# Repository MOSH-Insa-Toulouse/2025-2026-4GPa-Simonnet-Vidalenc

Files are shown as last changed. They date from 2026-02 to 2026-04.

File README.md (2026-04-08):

# Projet Capteur Low-Cost 4A Génie Physique - Max Simonnet & Basile Vidalenc

## Sommaire
- [Projet Capteur Low-Cost 4A Génie Physique - Max Simonnet \& Basile Vidalenc](#projet-capteur-low-cost-4a-génie-physique---max-simonnet--basile-vidalenc)
  - [Sommaire](#sommaire)
  - [1. Description du projet ](#1-description-du-projet-)
    - [1.1 Caractéristiques et travaux de recherche préliminaires sur le capteur ](#11-caractéristiques-et-travaux-de-recherche-préliminaires-sur-le-capteur-)
    - [1.2 Cours et formation ](#12-cours-et-formation-)
  - [2. Livrables du projet ](#2-livrables-du-projet-)
  - [3. Carte Arduino UNO et code associé ](#3-carte-arduino-uno-et-code-associé-)
  - [4. KiCad ](#4-kicad-)
    - [4.1. Symboles et empreintes des composants ](#41-symboles-et-empreintes-des-composants-)
    - [4.2. Schématique ](#42-schématique-)
    - [4.3. Placement des composants ](#43-placement-des-composants-)
  - [5. Fabrication du shield ](#5-fabrication-du-shield-)
    - [5.1 Réalisation du PCB ](#51-réalisation-du-pcb-)
    - [5.2 Perçage et soudure ](#52-perçage-et-soudure-)
  - [6. Logiciel de simulation LTSpice ](#6-logiciel-de-simulation-ltspice-)
  - [8. Tests et résultats ](#8-tests-et-résultats-)
    - [8.1 Banc de test ](#81-banc-de-test-)
    - [8.2 Résultats obtenus et analyses ](#82-résultats-obtenus-et-analyses-)
    - [8.3 Regard critique sur les résultats ](#83-regard-critique-sur-les-résultats-)
  - [9. Datasheet ](#9-datasheet-)

## 1. Description du projet 

Ce projet s'inscrit dans le cadre de l'unité de formation "Du capteur au banc de test en open source hardware". Ce cours est dispensé en quatrième année au sein du département de Génie Physique de l'INSA Toulouse et a pour but de nous sensibiliser aux différentes étapes de conception et d'analyse utiles à la création d'un capteur.

### 1.1 Caractéristiques et travaux de recherche préliminaires sur le capteur 

Le KTY2000 est un exemple de technologie low-tech à base de graphite. Ce projet s’inspire du travail mené par plusieurs scientifiques et publié dans [cet article](https://www.nature.com/articles/srep03812) en 2014. En effet, les études ont révélé les nombreux avantages du carbone graphite. L’électronique à base de papier attire de plus en plus les ingénieur.es de par sa facilité d’approvisionnement, de fabrication et son faible coût. Il suffit dans notre cas de déposer une fine couche de graphite sur le substrat naturellement poreux pour former la base du capteur. Les mines de crayon sont constituées de réseaux percolés de fines poudres de graphite liées entre elles par des argiles, permettant d’obtenir après dépôt de fins films conducteurs non fabriqués en laboratoire. 

Le système à l’étude est granulaire, autrement dit il existe une dépendance entre la conductivité électrique (notamment par effet tunnel) et l’espace moyen entre les nanoparticules de graphite. Ainsi, une déformation de la feuille de papier va modifier la conductivité globale de la couche de graphite, induisant des changements de résistances réversibles lors des déformations en compression ou en traction. Ceci constitue en fait le principe d'une jauge de contrainte. 
L’expérience est réalisée avec différentes duretés de mine de crayon (2H, HB, 2B). Les mesures de résistance pour chaque crayon sont réalisées en fonction de différents rayons de courbure (soit la déformation) ou de l’angle de flexion de notre capteur. Cela permet une caractérisation complète de chaque type de crayon et ainsi de notre capteur. 

Dans notre cas, les traces de crayon sont déposées sur du papier comme vu ci-dessous. Une fois colorié, le capteur est connecté à un système de mesures externe via des pinces crocodiles reliées à un PCB et branché sur une carte Arduino Uno.

<p align="center">

### 1.2 Cours et formation 

Pour mener ce projet, nous avons d'abord suivi différents cours et TPs.
- Introduction à la chaîne de mesure
- TP développement d'un capteur à jauge de contrainte à base de crayon graphite
- TP conception d'un circuit analogique pour interfacer le capteur à jauge de contrainte
- TP programmation de microcontrôleurs et développement d'un matériel open source
- TP LTSpice afin de simuler le fonctionnement du circuit électronique comprenant la jauge de contrainte
- TP shield électronique PCB dédié à l'interface du capteur de contrainte
- TP réalisation du banc de test de la jauge de contrainte
- Cours fiche technique de la jauge de contrainte
- Cours Github

<p align="center">

## 2. Livrables du projet 

* Un shield PCB devra être designé et fabriqué. Il sera ensuite connecté à une plaque Arduino UNO. Le shield doit contenir au minimum un amplificateur transimpédence, un module Bluetooth, un écran OLED et un encodeur rotatoire pour la calibration du capteur.

* La carte Arduino fonctionnera avec un code permettant de mesurer la containte appliquée sur le capteur. La carte devra aussi communiquer avec le module Bluetooth, et contrôler et communiquer avec l'écran OLED grâce à l'encodeur rotatoire.

* Une application Android APK
* Un protocole de test
* La datasheet du capteur de contrainte

## 3. Carte Arduino UNO et code associé 

Le code Arduino est consultable [ici]().
Ce code permet la réception des mesures faites par les deux capteurs, la conversion résistance-angle du flex-sensor et celle tension-résistance pour le KTY2000, la gestion de l'affichage sur l'écran OLED et l'envoi de données via un port série.

## 4. KiCad 

Voici la liste des différents composants présents sur notre PCB :

- _x2 résistance 100kΩ_
- _x1 résistance 47kΩ_
- _x1 résistance 10kΩ_
- _x1 résistance 1kΩ_
- _x1 résistance variable MCP41010_
- _x1 capacité 1μF_
- _x2 capacité 100nF_
- _x1 amplificateur opérationnel LTC1050_
- _x1 écran OLED I2C 1306_
- _x1 encodeur rotatoire_
- _x1 servo-moteur_
- _x1 capteur graphite_

### 4.1. Symboles et empreintes des composants 
 
* Amplificateur LTC1050
* MCP41010
* Ecran OLED
* Flex sensor
* Bluetooth HC-05

### 4.2. Schématique 
 
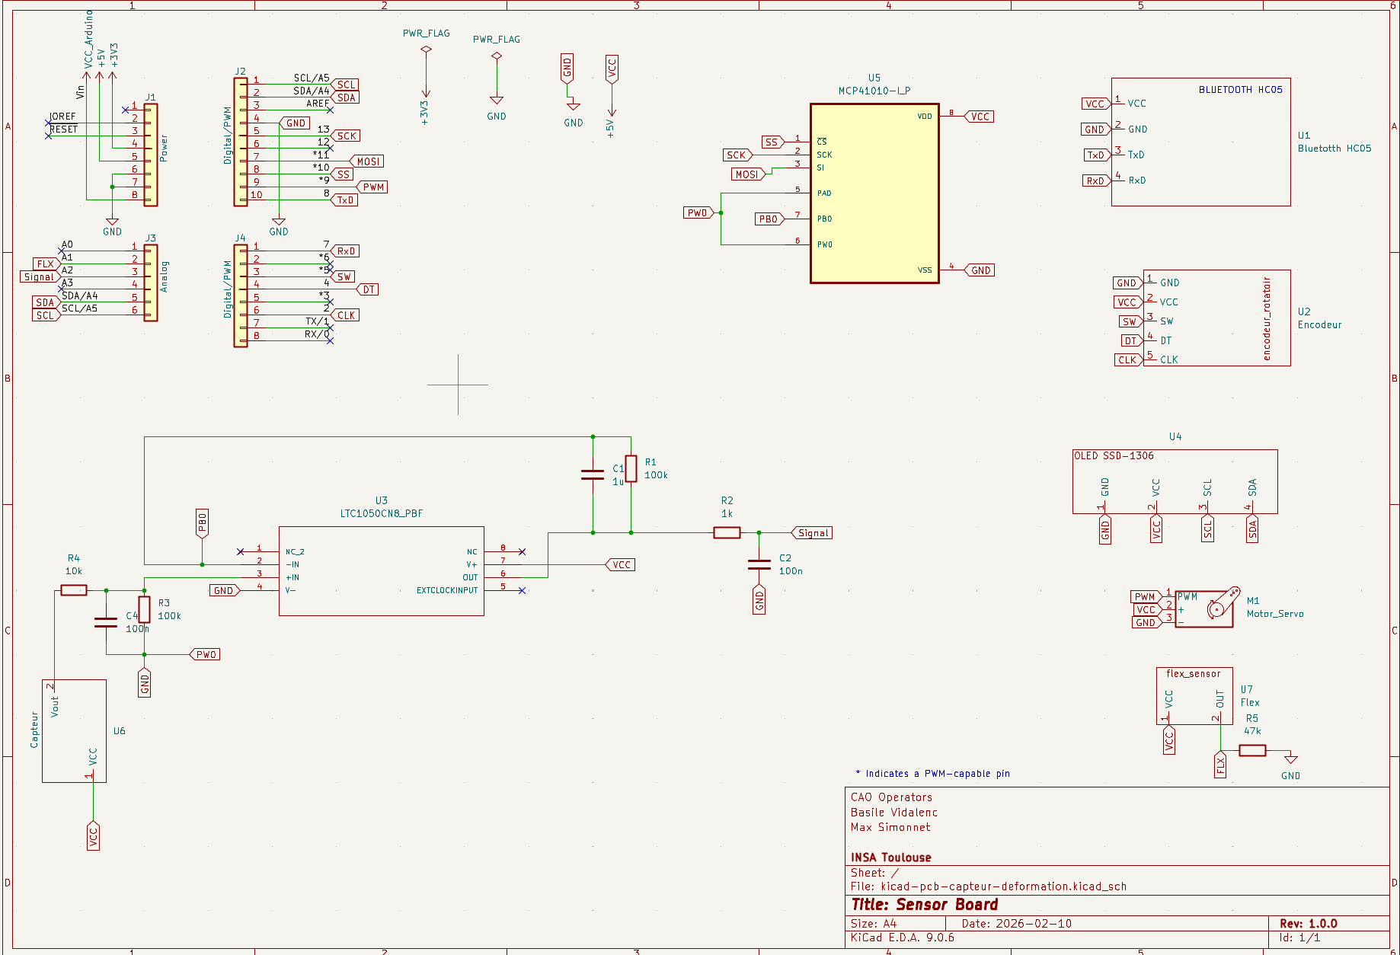
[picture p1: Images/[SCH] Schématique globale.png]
<p align="center">

* Amplificateur LTC1050
<p> 
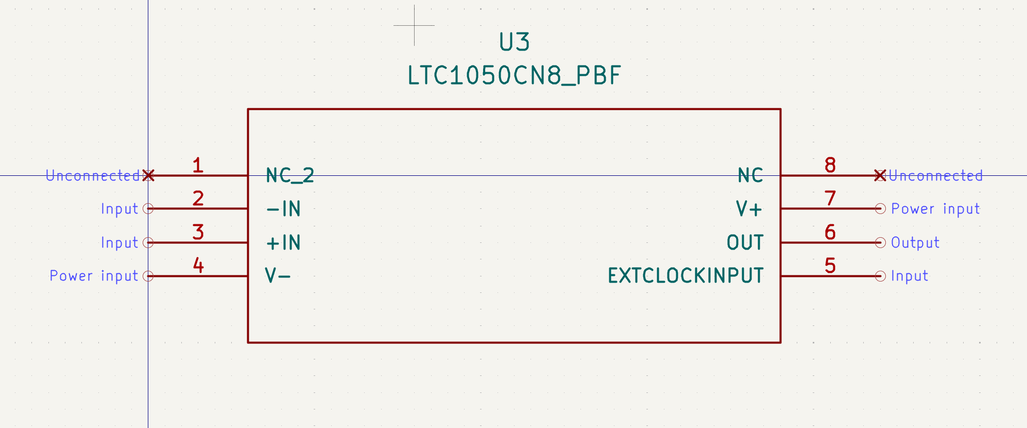
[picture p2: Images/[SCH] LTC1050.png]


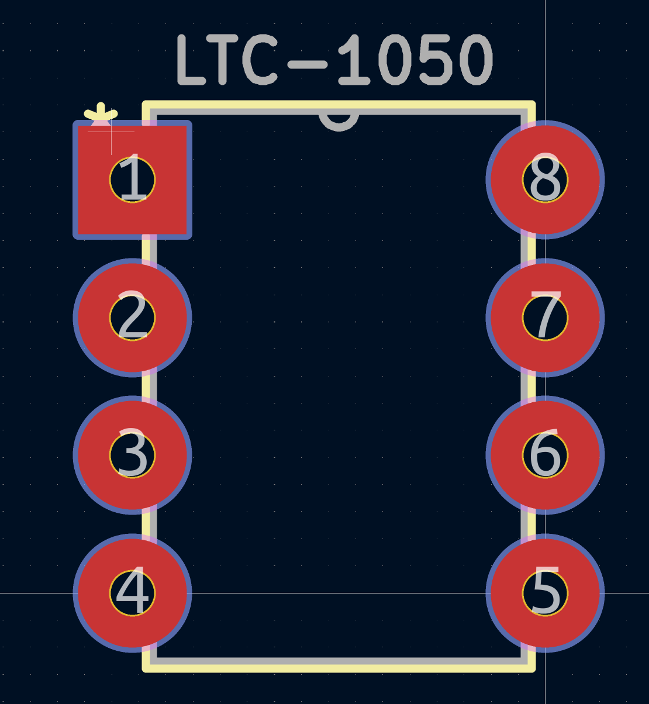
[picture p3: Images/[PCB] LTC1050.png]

</p>

* MCP41010
 <p> 
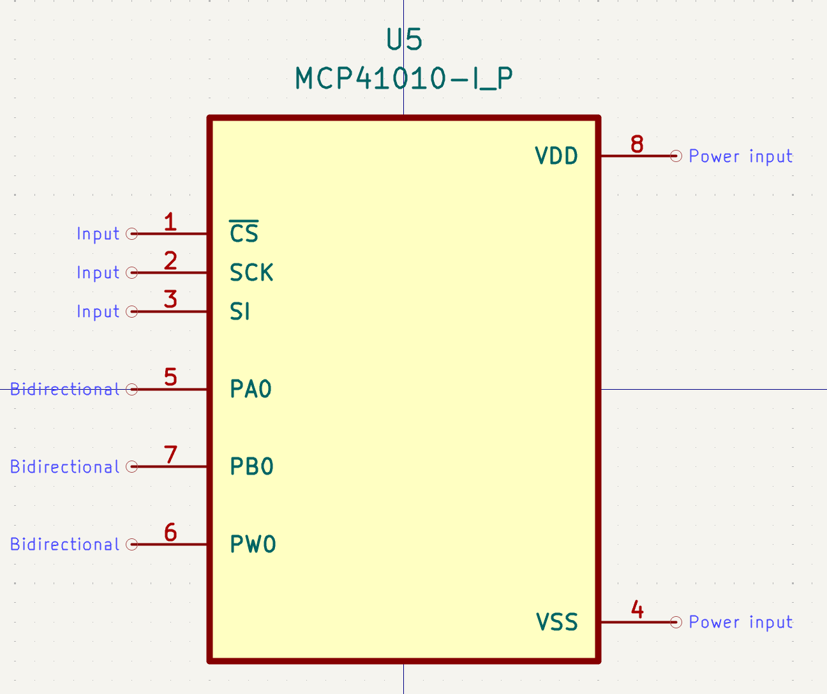
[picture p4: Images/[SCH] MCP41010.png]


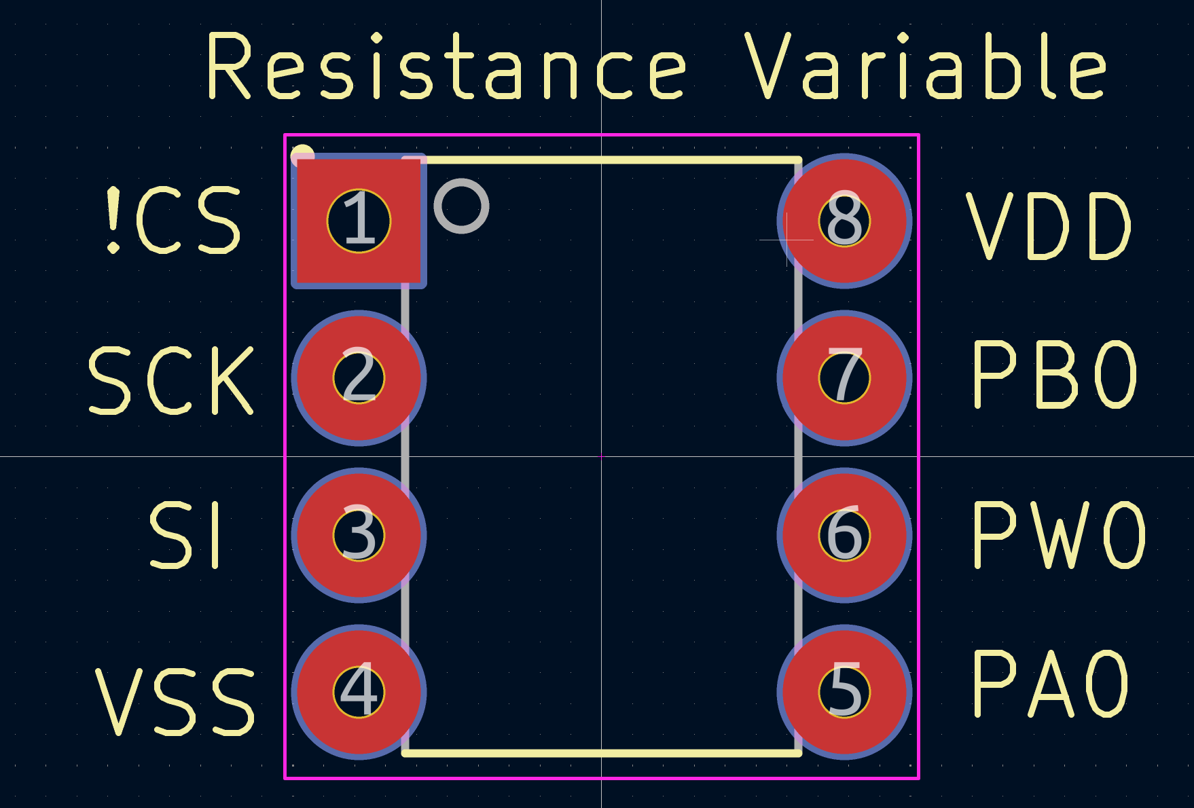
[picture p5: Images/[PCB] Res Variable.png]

</p>

* Ecran OLED
 <p> 
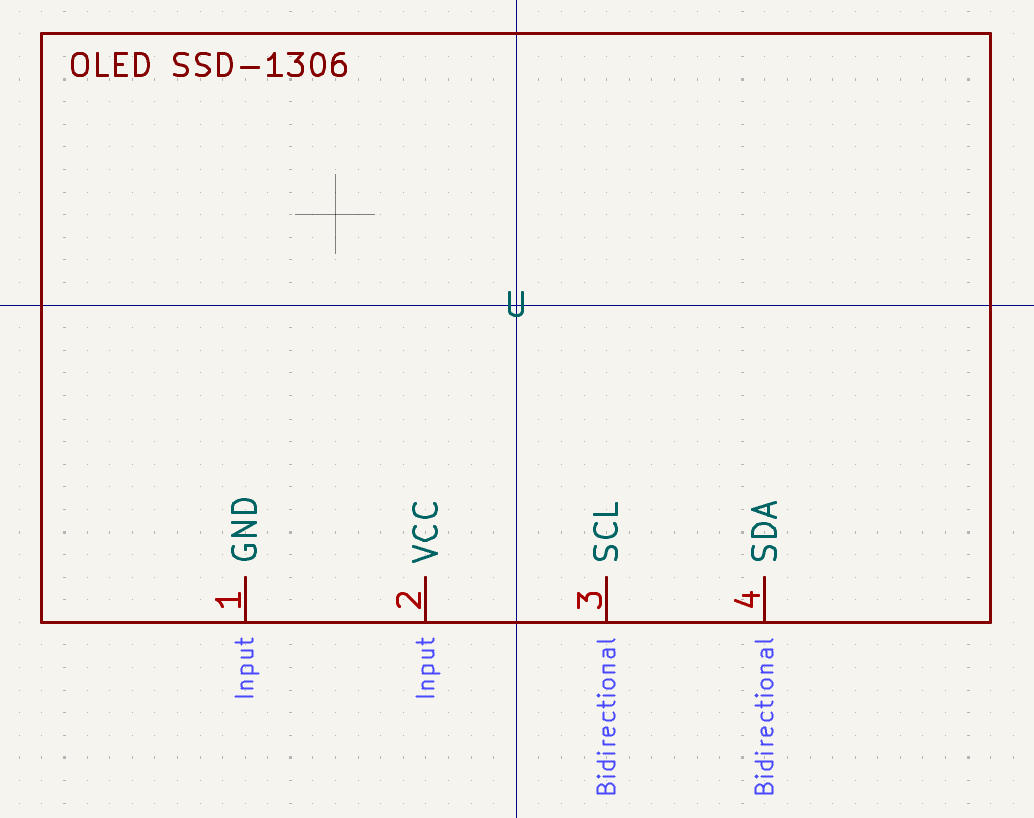
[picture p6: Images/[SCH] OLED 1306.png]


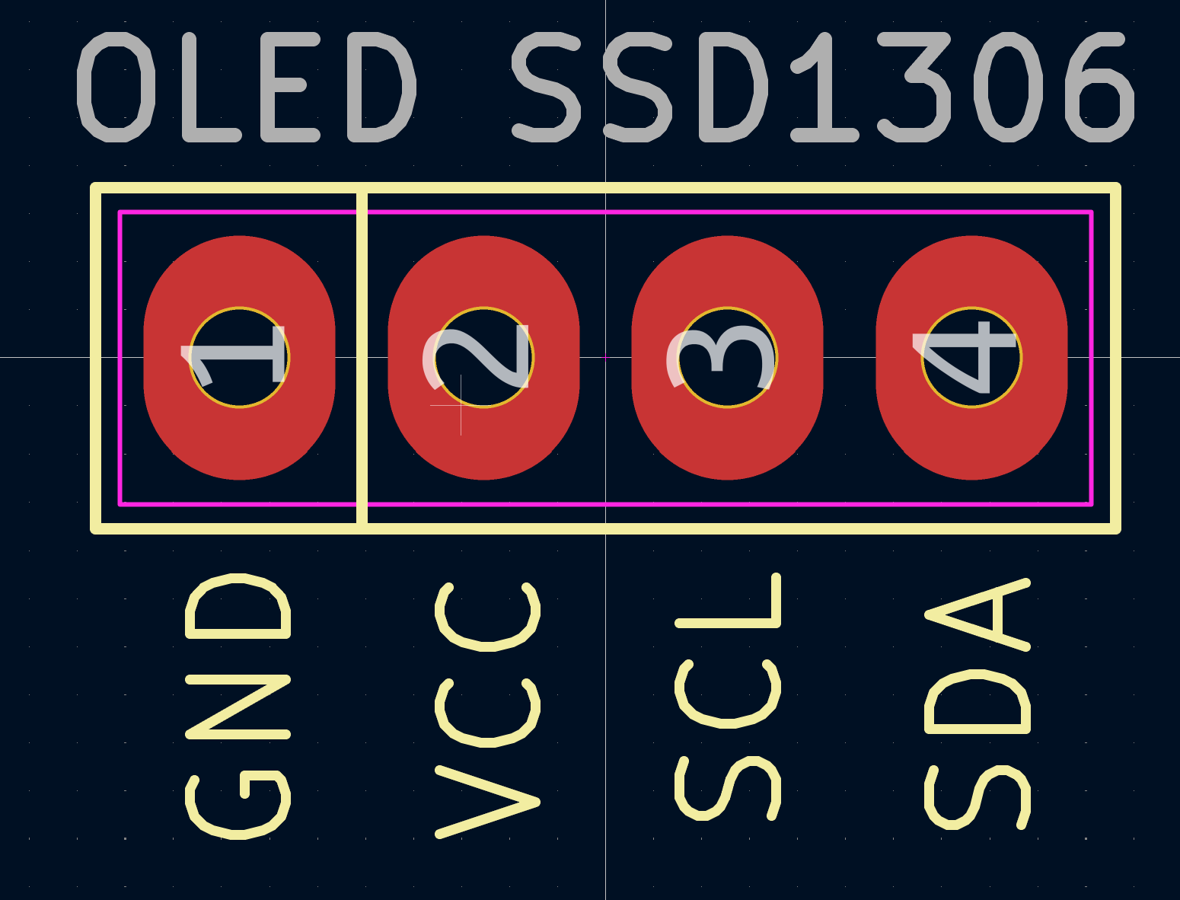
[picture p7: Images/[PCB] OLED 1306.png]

</p>

* Flex sensor
 <p> 
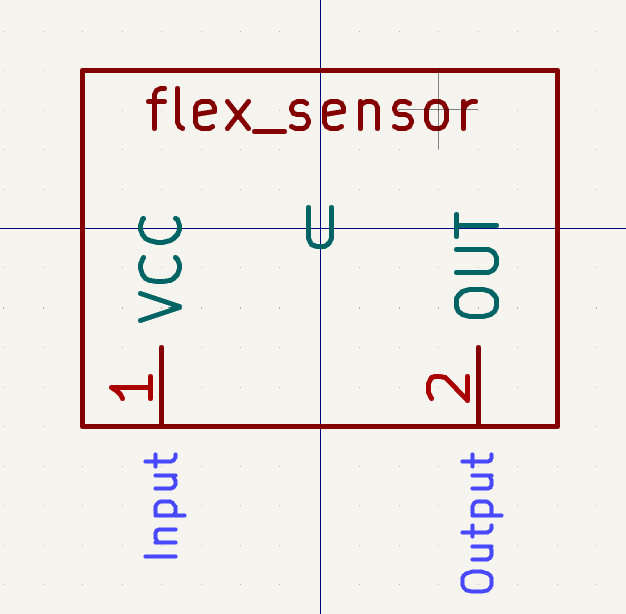
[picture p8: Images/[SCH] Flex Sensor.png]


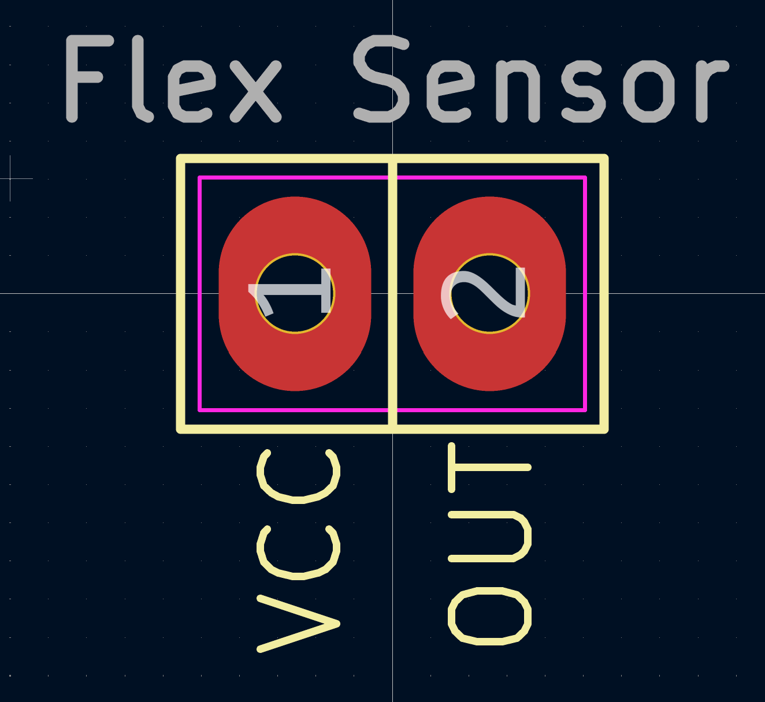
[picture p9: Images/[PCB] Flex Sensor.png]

</p>

* Bluetooth HC-05
 <p> 
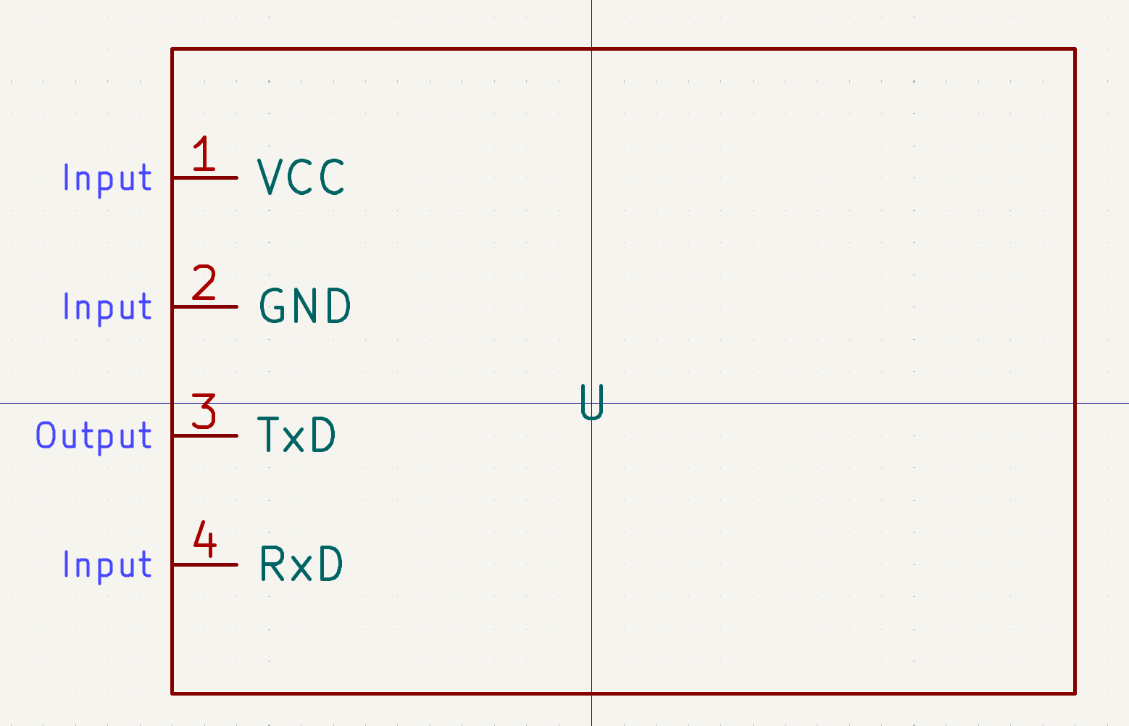
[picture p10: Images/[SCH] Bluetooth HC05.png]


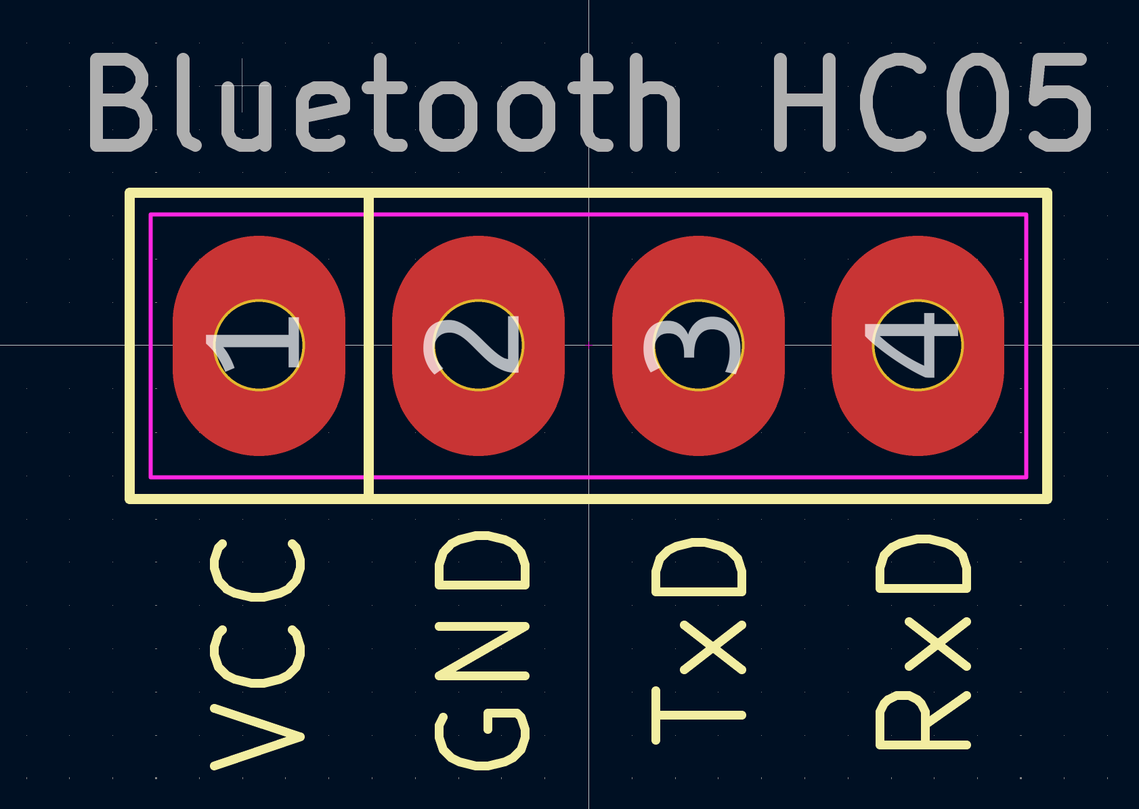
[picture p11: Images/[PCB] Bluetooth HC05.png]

</p>

### 4.3. Placement des composants 
 
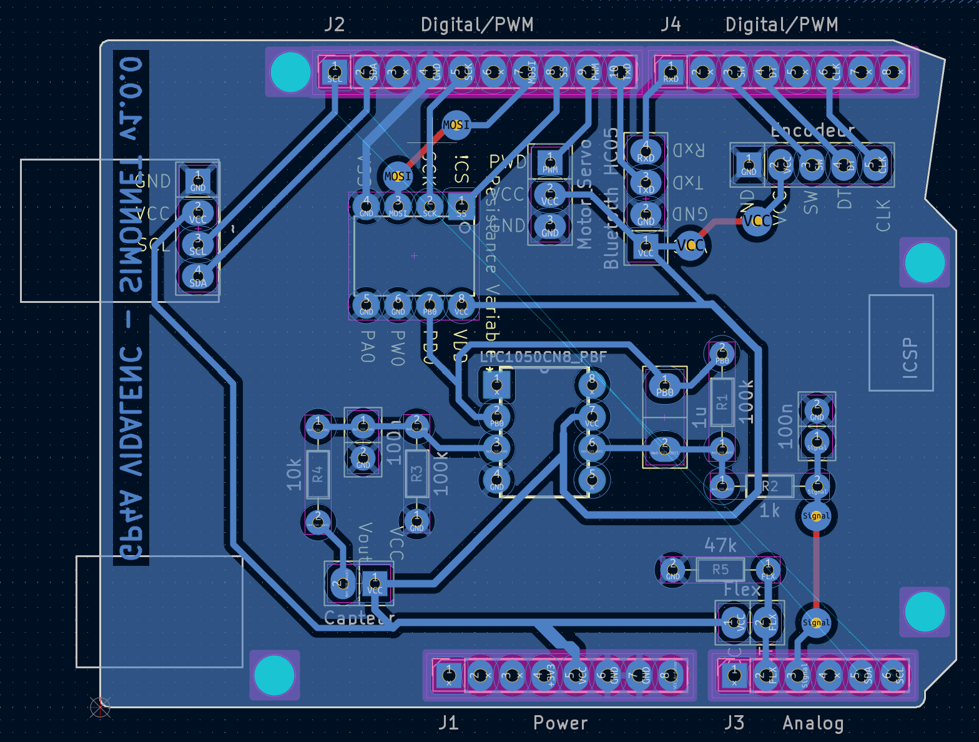
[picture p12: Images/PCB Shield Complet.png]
<p align="center">

## 5. Fabrication du shield 
 
### 5.1 Réalisation du PCB 

Le PCB a été fabriqué grâce au matériel mis à disposition au Génie Physique et au Génie Électrique et Informatique de l'INSA Toulouse. Les manipulations ont été faites avec l'aide de Catherine Crouzet. La modélisation du PCB fait sur [KiCad]() a été imprimée sur du papier calque tranparent. Ce motif a été ensuite transféré par UVs sur la plaquette d'epoxy finement recouverte d'une couche de cuivre. À l'aide d'un révelateur, la partie non insolée de la résine a été retirée. La plaquette d'expoxy a été ensuite placée dans un bain de perchlorure de fer pour que le cuivre non protégé par la résine soit retiré de la plaquette. Enfin, la plaque a été nettoyée des dernières traces de résine avec de l'acétone.

Par soucis de convention, les pattes "1" de chaque composant sont en forme de carré

### 5.2 Perçage et soudure 

⌀ 1.0mm : Broches de connexion de la carte Arduino Uno

⌀ 0.8mm : Circuit intérieur du PCB 

## 6. Logiciel de simulation LTSpice 
 
L'ensemble de notre circuit électronique a été simulé sur le logiciel LTSpice afin de comprendre et d'analyser son comportement dans des conditions réelles de valeurs de tension. Les différentes simulations ont permis d'une part de vérifier le bon fonctionnement du circuit et de chacun des composants intégrés, et d'autre part de comprendre l'utilité de chacun. Les images ci-dessous représentent la schématique du circuit. Se référer à la [datasheet] pour de plus amples informations.

## 8. Tests et résultats 

Setup d'utilisation du KTY2000.

### 8.1 Banc de test 

### 8.2 Résultats obtenus et analyses 

Les deux graphes suivant représentent la variation de la résistance relative (en %) en fonction de la déformation appliquée - compression et traction.

Les mines les plus tendres contiennent une proportion plus élevée de particules de graphite. C’est donc pour cette raison que les traces de ce type de crayon paraissent plus foncées sur le papier. À l’inverse, les mines les plus dures contiennent beaucoup de liants argileux et apparaissent plus claires. Cela explique également que les résistances de mines de crayon les plus tendres sont plus faibles que les mines de crayon les plus dures. En effet, sous la traction, les particules de graphite sont davantage écartées les unes des autres favorisant la déconnexion des voies de conduction : le courant est donc minime, la résistance quant à elle augmente.  Sous compression, les particules de graphite contenues dans la trace de crayon se rapprochent, facilitant la conduction du courant à travers le réseau de percolation : la résistance s’abaisse naturellement.

Cette caractéristique est illustrée à travers la variation relative de résistance en fonction de la déformation du capteur. En effet, un crayon qui contient moins de particules de graphite comme le 2H dépose naturellement moins de graphite sur le substrat. Les variations de résistance sont donc plus significatives comme beaucoup de chemins de percolations sont créés ou rompus contrairement au 2B où les déformations n’induisent que de faibles variations relatives de résistance.
 
Il est également notable que le comportement en compression du flex-sensor se rapproche de celui du KTY2000. Nous pouvons en conclure que notre capteur graphite présente des similarités de fonctionnnement qu'un capteur industriel. **Cela confirme l'idée que le low-tech est une alternative pertinente pour le futur de l'industrie.**

### 8.3 Regard critique sur les résultats 
 
Il est important de souligner la variabilité des conditions expérimentales. Entre chaque relevé de points et malgré le fait que les pinces crocodiles sans dents étaient bien fixées, il se peut que l’attache du capteur ait bougée. Les résultats sont imprécis et pour certains discutables au vu de la qualité du montage mais suivent tout de même les lois physiques. 

Nous pourrions amener plusieurs pistes d'améliorations à notre projet :

- Améliorer notre banc de test afin de garantir des résultats optimaux mais surtout pour augmenter sa durée de vie et sa résistance. Par exemple, nous pourrions concevoir de le fabriquer par l'intermédiaire d'une imprimante 3D. 

- Améliorer le setup expérimental en commençant par l'ergonomie de notre PCB afin de le rendre plus fonctionnel pour la réalisation des mesures de résistance. Penser à un meilleur emplacement pour les différents composants, à un système d'accroche pour l'écran OLED, mais aussi pour les pinces crocodile dans le but de limiter le plus possible la variabilité des conditions expérimentales. 

## 9. Datasheet 
 
La datasheet du KTY2000 est consultable [ici]. Elle reprend tous les concepts physiques ainsi que les résultats de mesures et leur analyse. D'autres courbes illustrant la variation de résistance en fonction de l'angle de flexion y figurent, venant compléter les affirmations énoncées tout au long de ce rendu.

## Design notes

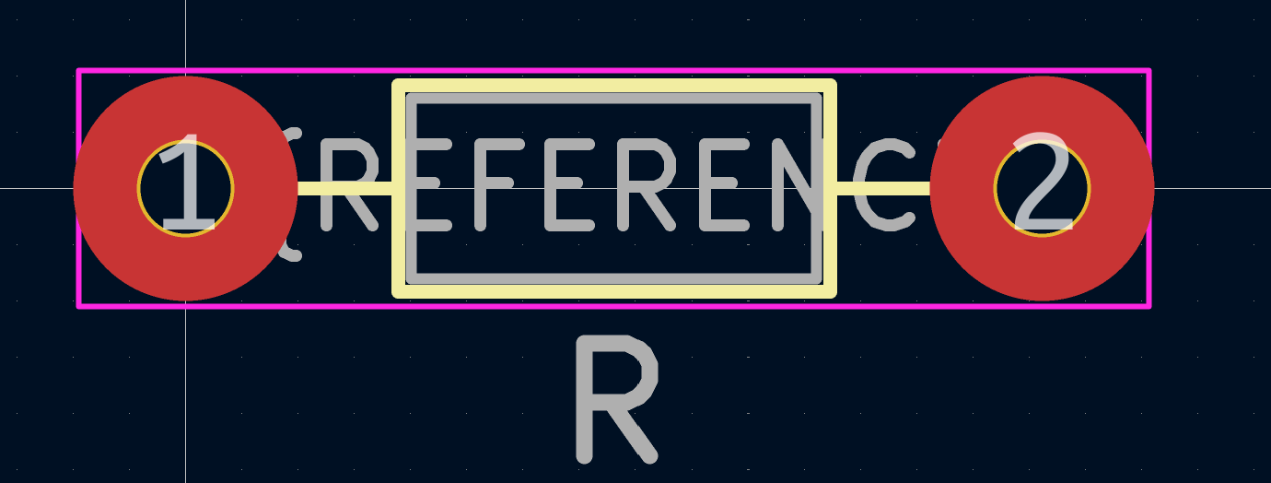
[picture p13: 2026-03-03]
Images/[PCB] Resistance.png

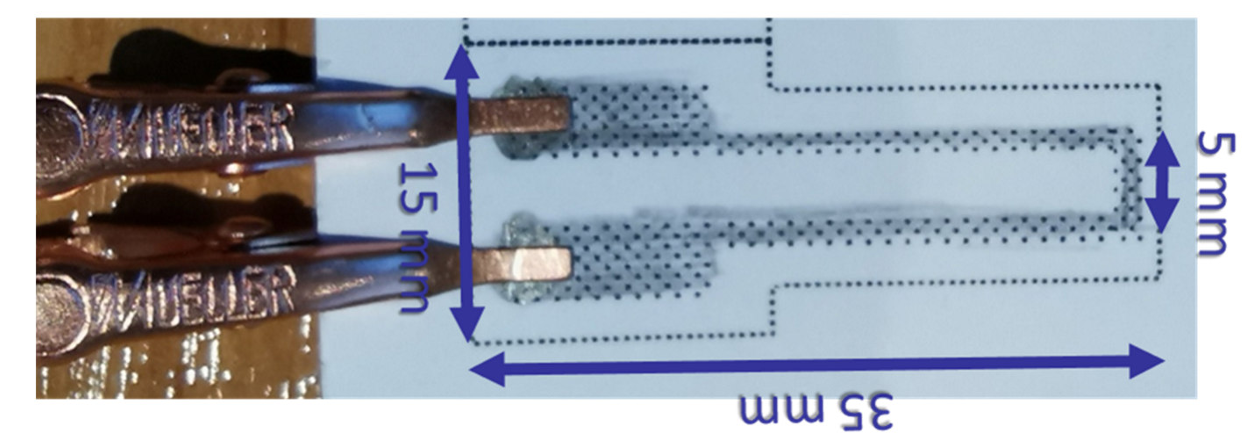
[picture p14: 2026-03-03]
Images/Dimensions Capteur graphite.png

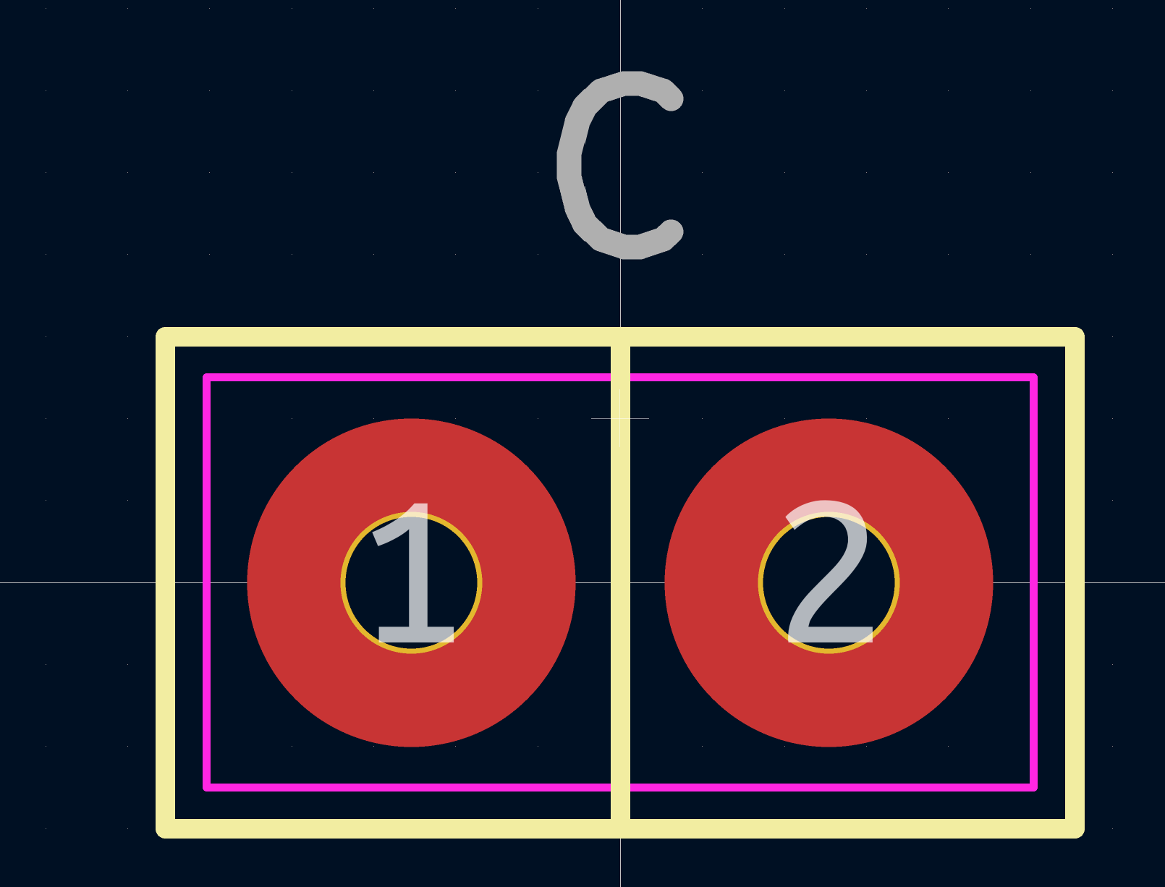
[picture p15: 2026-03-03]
Images/[PCB] Condo souple.png

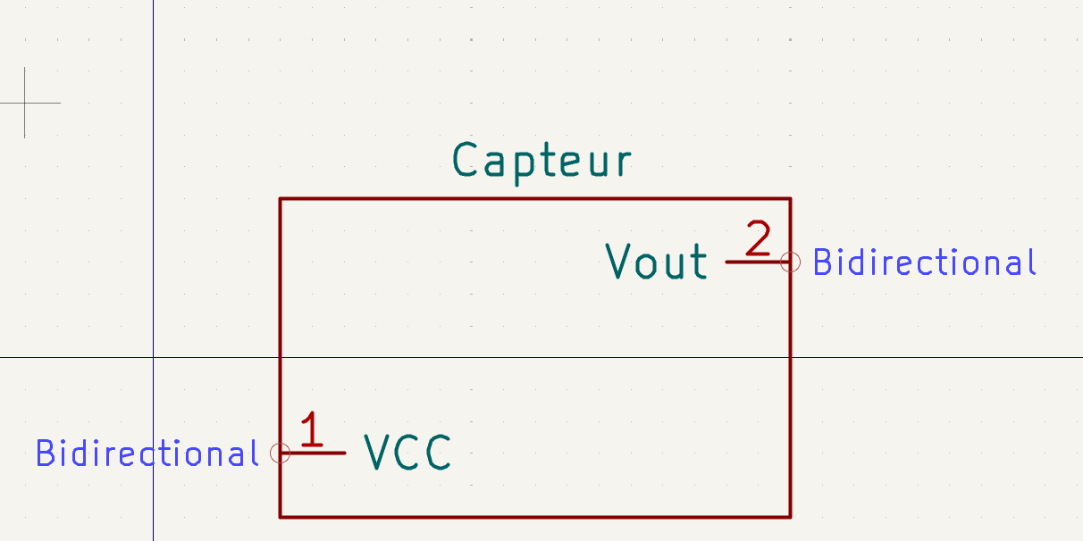
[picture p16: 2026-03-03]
Images/[SCH] Capteur graphite.png

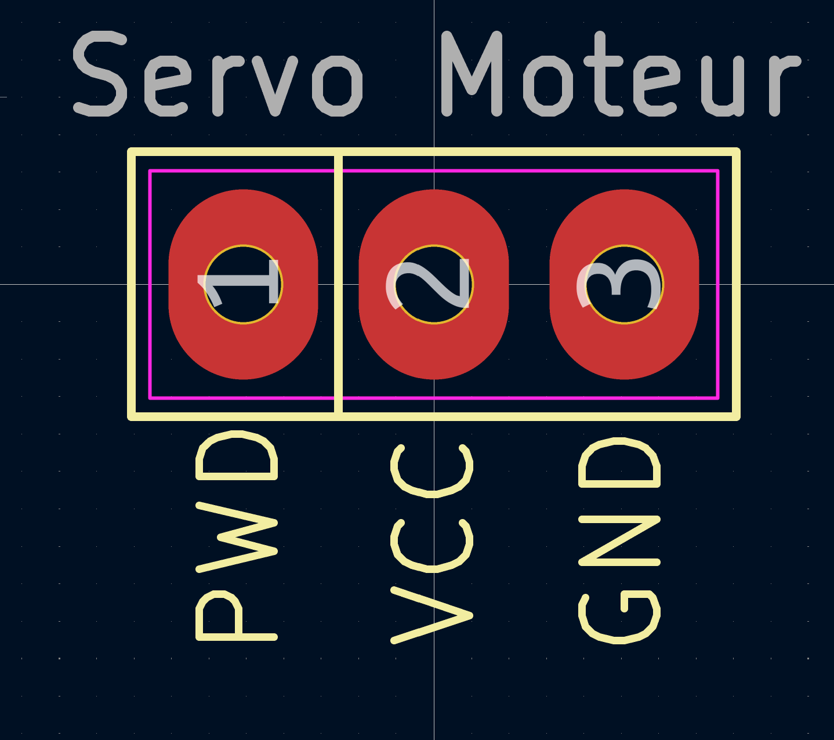
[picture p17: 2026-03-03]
Images/[PCB] Servo-Moteur.png

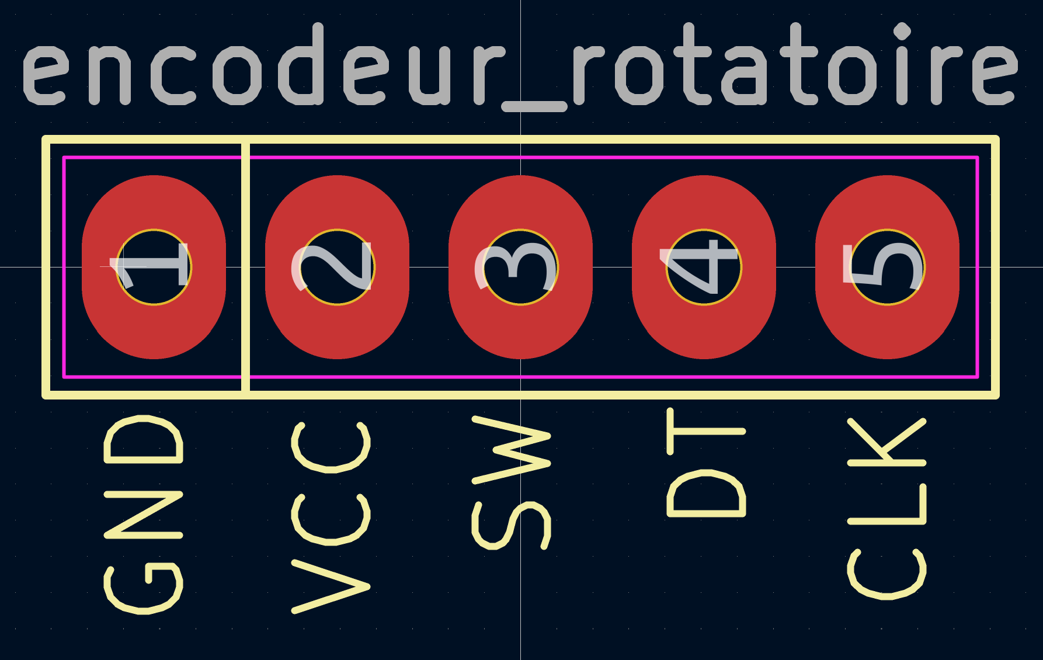
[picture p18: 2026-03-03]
Images/[PCB] Encodeur rotatoire.png

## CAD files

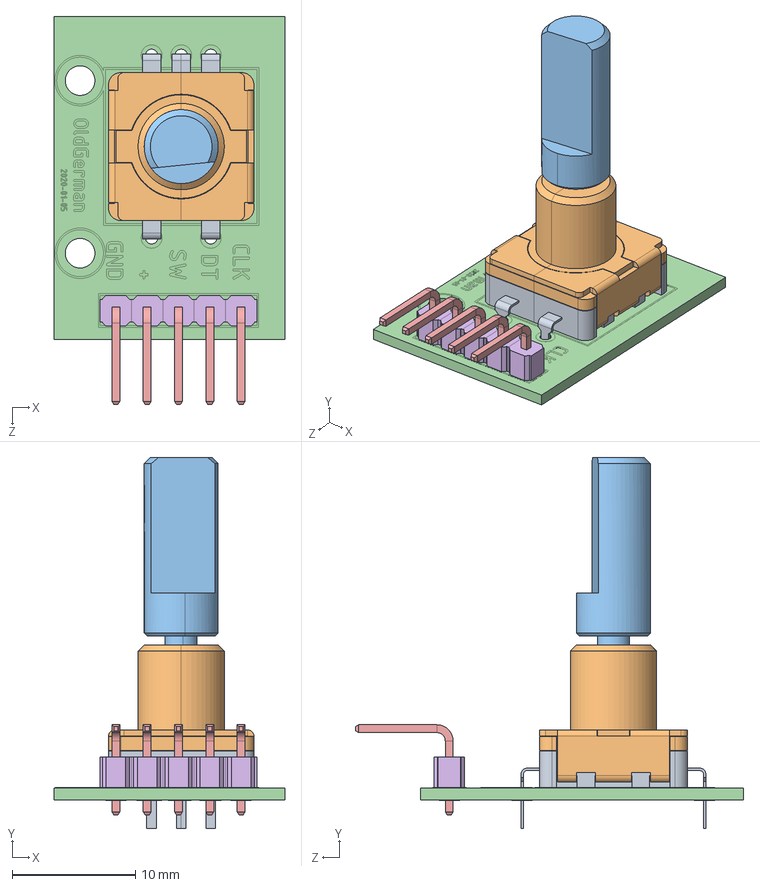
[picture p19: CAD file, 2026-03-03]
kicad-pcb-capteur-deformation/encodeur-rotatoire/KY-040 Rotary Encoder.STEP
18.7 x 30.1 x 31.5 mm
Rotary Encoder
D-handle
pcb
2.54 5PIN 90

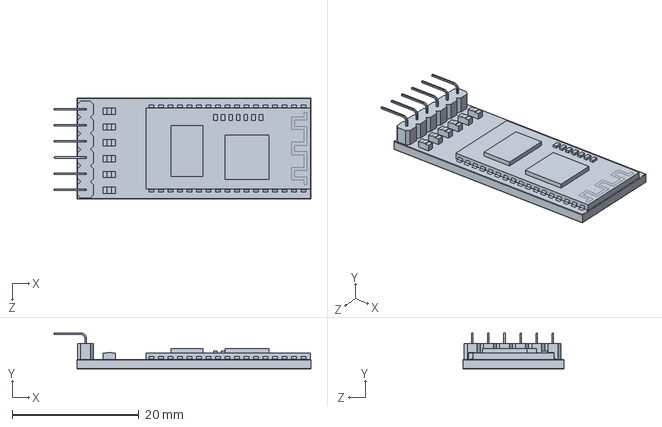
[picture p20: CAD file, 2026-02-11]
kicad-pcb-capteur-deformation/hc05-bluetooth/HC05.STEP
40.6 x 5.67 x 16.0 mm

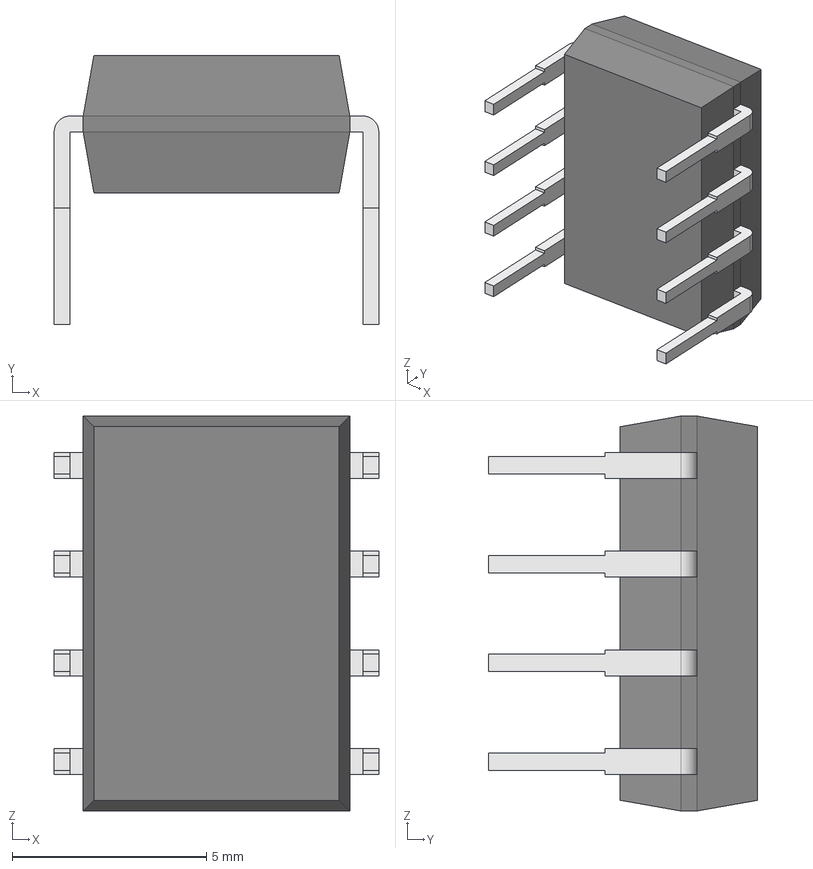
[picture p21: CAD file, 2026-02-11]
kicad-pcb-capteur-deformation/LTC1050CN8_PBF/LTC1050CN8_PBF.step
8.35 x 6.93 x 10.2 mm
Body001 (Mirror #1) x 5

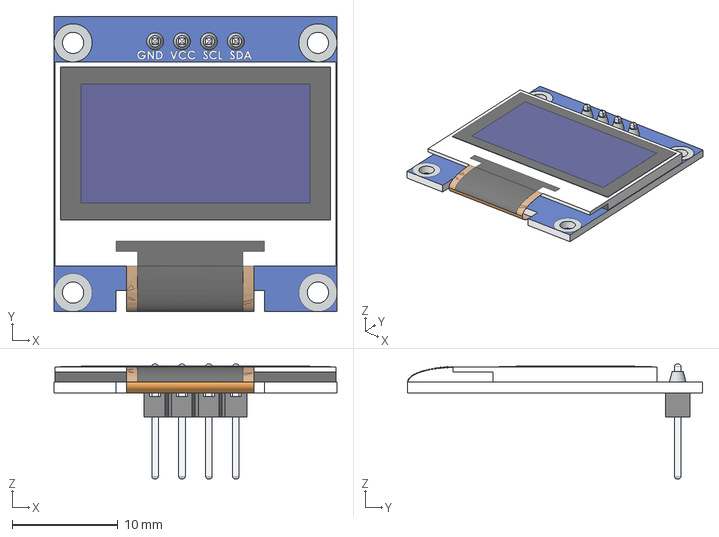
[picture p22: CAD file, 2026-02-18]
kicad-pcb-capteur-deformation/OLED SSD1306/OLED-128x64-0.96.step
26.7 x 27.9 x 10.8 mm

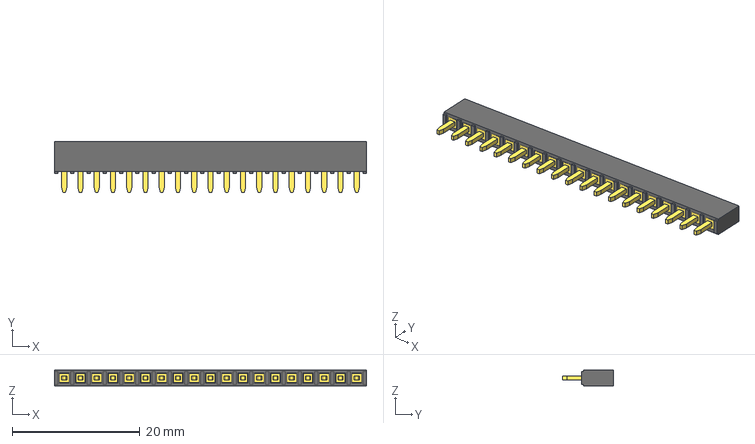
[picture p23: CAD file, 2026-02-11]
kicad-pcb-capteur-deformation/pin-header-female-2-54mm-different-pin-numbers-1.snapshot.4/19-Pin Header - Female - 2.54mm.step
48.8 x 8.00 x 2.50 mm

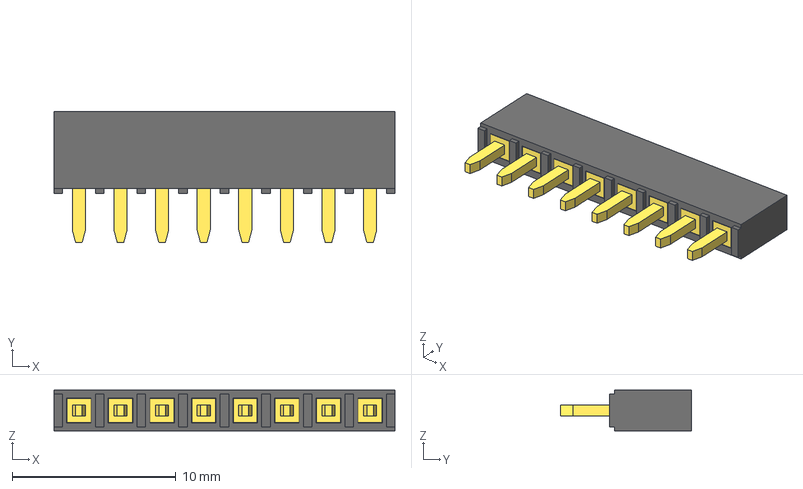
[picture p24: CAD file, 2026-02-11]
kicad-pcb-capteur-deformation/pin-header-female-2-54mm-different-pin-numbers-1.snapshot.4/8-Pin Header - Female - 2.54mm.step
20.8 x 8.00 x 2.50 mm

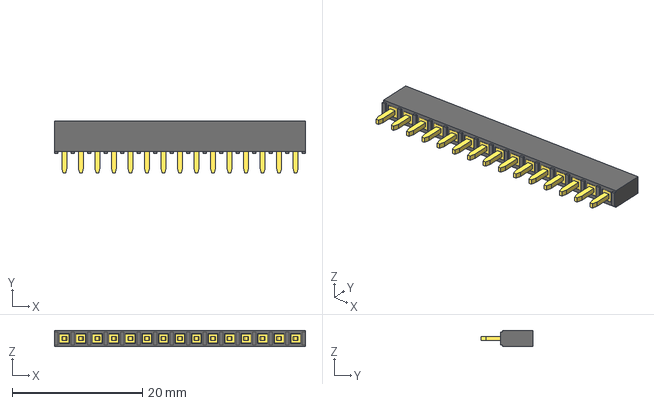
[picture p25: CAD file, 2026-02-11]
kicad-pcb-capteur-deformation/pin-header-female-2-54mm-different-pin-numbers-1.snapshot.4/15-Pin Header - Female - 2.54mm.step
38.6 x 8.00 x 2.50 mm

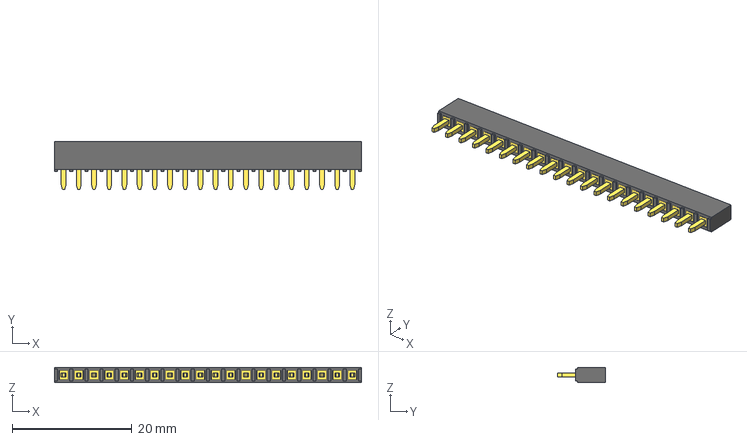
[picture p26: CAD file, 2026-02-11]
kicad-pcb-capteur-deformation/pin-header-female-2-54mm-different-pin-numbers-1.snapshot.4/20-Pin Header - Female - 2.54mm.step
51.3 x 8.00 x 2.50 mm

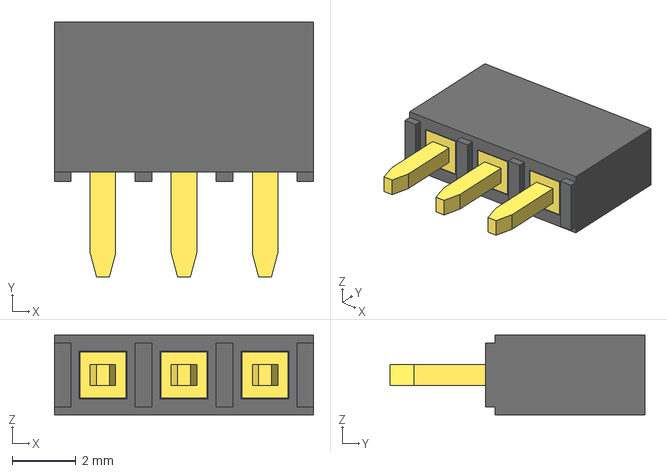
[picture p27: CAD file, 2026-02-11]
kicad-pcb-capteur-deformation/pin-header-female-2-54mm-different-pin-numbers-1.snapshot.4/3-Pin Header - Female - 2.54mm.step
8.12 x 8.00 x 2.50 mm

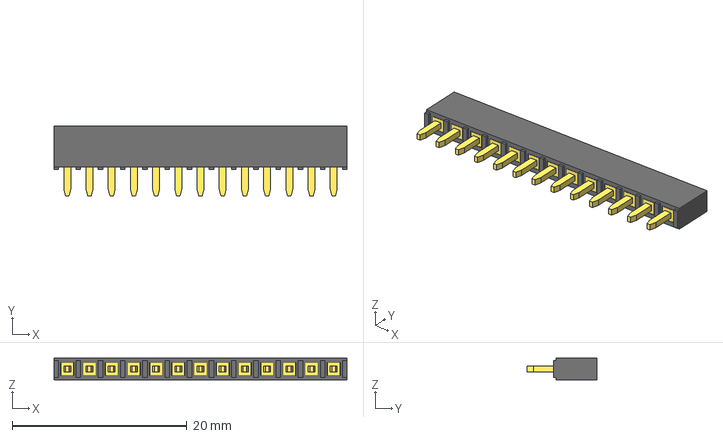
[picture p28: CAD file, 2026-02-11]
kicad-pcb-capteur-deformation/pin-header-female-2-54mm-different-pin-numbers-1.snapshot.4/13-Pin Header - Female - 2.54mm.step
33.5 x 8.00 x 2.50 mm

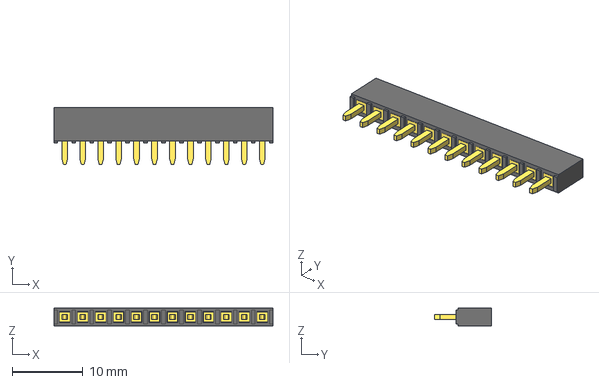
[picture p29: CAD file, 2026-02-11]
kicad-pcb-capteur-deformation/pin-header-female-2-54mm-different-pin-numbers-1.snapshot.4/12-Pin Header - Female - 2.54mm.step
31.0 x 8.00 x 2.50 mm

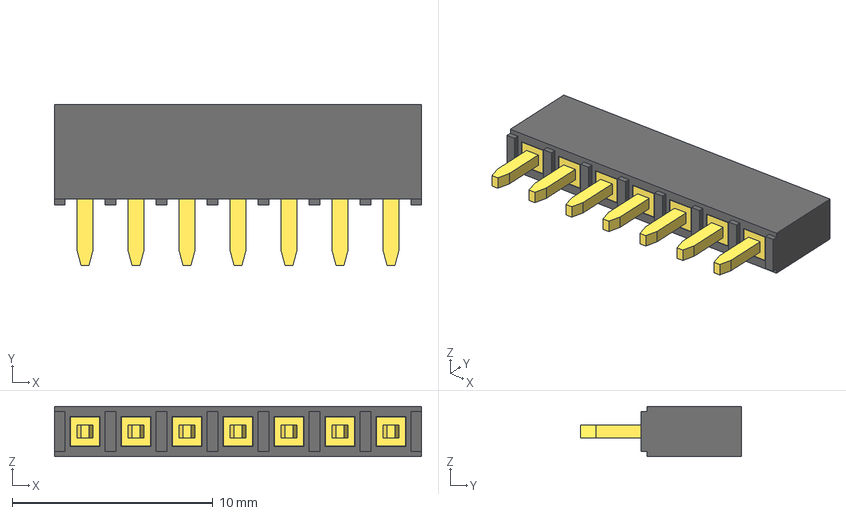
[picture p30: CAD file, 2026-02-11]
kicad-pcb-capteur-deformation/pin-header-female-2-54mm-different-pin-numbers-1.snapshot.4/7-Pin Header - Female - 2.54mm.step
18.3 x 8.00 x 2.50 mm

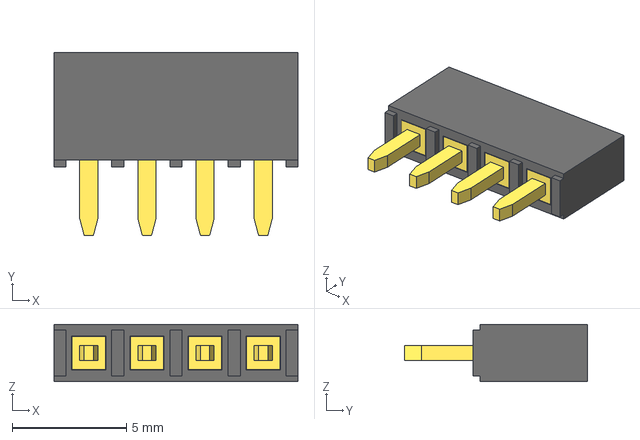
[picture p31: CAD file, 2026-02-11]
kicad-pcb-capteur-deformation/pin-header-female-2-54mm-different-pin-numbers-1.snapshot.4/4-Pin Header - Female - 2.54mm.step
10.7 x 8.00 x 2.50 mm

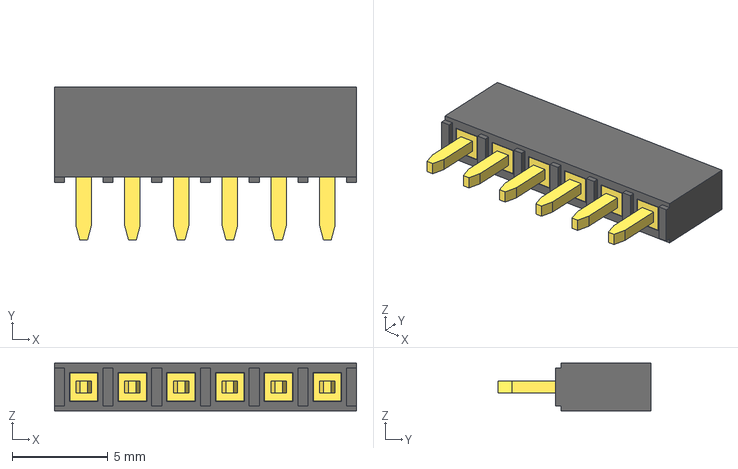
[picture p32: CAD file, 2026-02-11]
kicad-pcb-capteur-deformation/pin-header-female-2-54mm-different-pin-numbers-1.snapshot.4/6-Pin Header - Female - 2.54mm.step
15.7 x 8.00 x 2.50 mm

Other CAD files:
kicad-pcb-capteur-deformation/pin-header-female-2-54mm-different-pin-numbers-1.snapshot.4/14-Pin Header - Female - 2.54mm.step
kicad-pcb-capteur-deformation/pin-header-female-2-54mm-different-pin-numbers-1.snapshot.4/2-Pin Header - Female - 2.54mm.step
kicad-pcb-capteur-deformation/pin-header-female-2-54mm-different-pin-numbers-1.snapshot.4/10-Pin Header - Female - 2.54mm.step
kicad-pcb-capteur-deformation/pin-header-female-2-54mm-different-pin-numbers-1.snapshot.4/11-Pin Header - Female - 2.54mm.step
kicad-pcb-capteur-deformation/MCP41010-I_P/MCP41010-I_P.step
kicad-pcb-capteur-deformation/pin-header-female-2-54mm-different-pin-numbers-1.snapshot.4/16-Pin Header - Female - 2.54mm.step
kicad-pcb-capteur-deformation/pin-header-female-2-54mm-different-pin-numbers-1.snapshot.4/17-Pin Header - Female - 2.54mm.step
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

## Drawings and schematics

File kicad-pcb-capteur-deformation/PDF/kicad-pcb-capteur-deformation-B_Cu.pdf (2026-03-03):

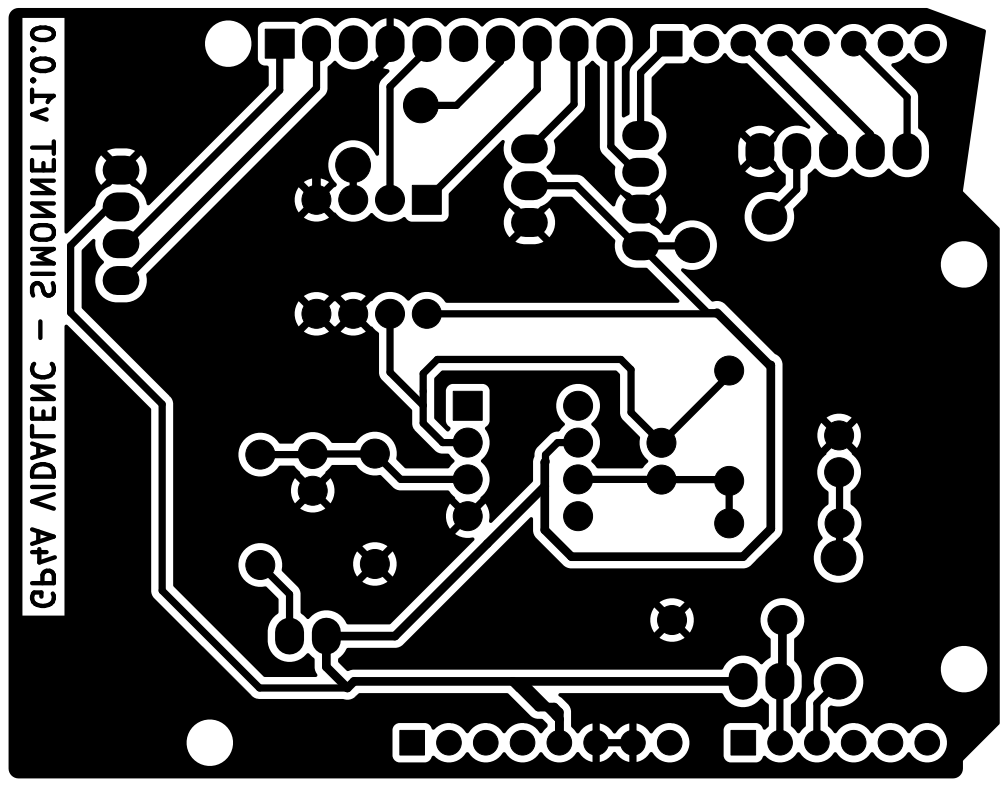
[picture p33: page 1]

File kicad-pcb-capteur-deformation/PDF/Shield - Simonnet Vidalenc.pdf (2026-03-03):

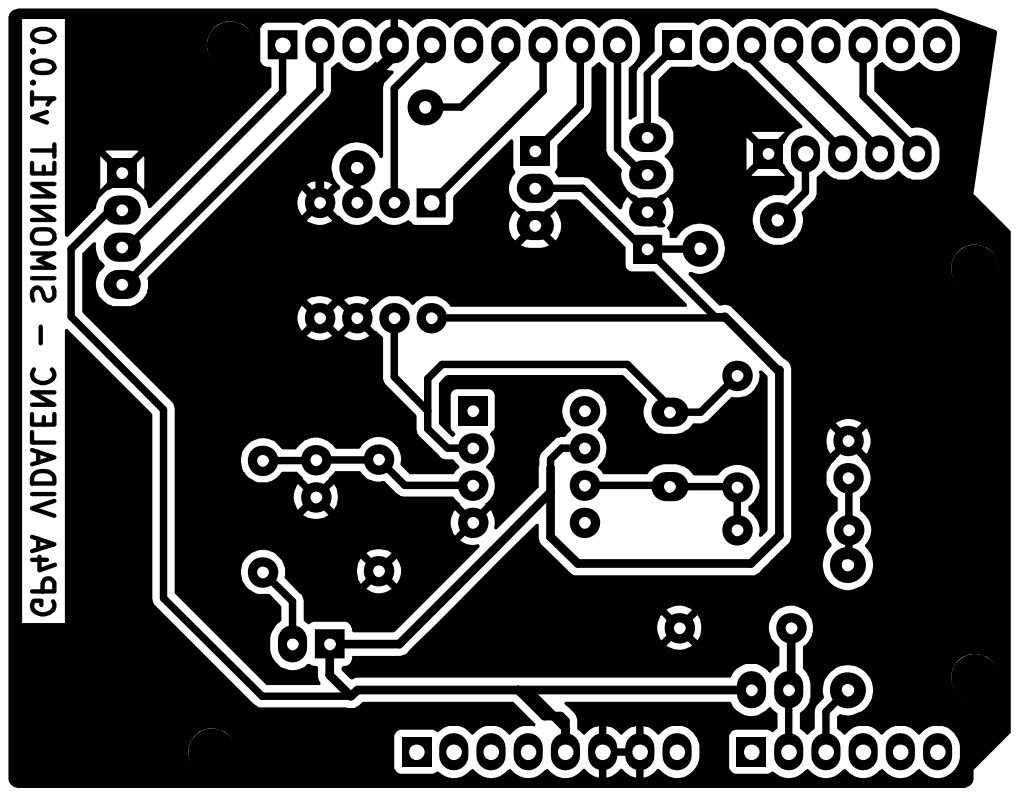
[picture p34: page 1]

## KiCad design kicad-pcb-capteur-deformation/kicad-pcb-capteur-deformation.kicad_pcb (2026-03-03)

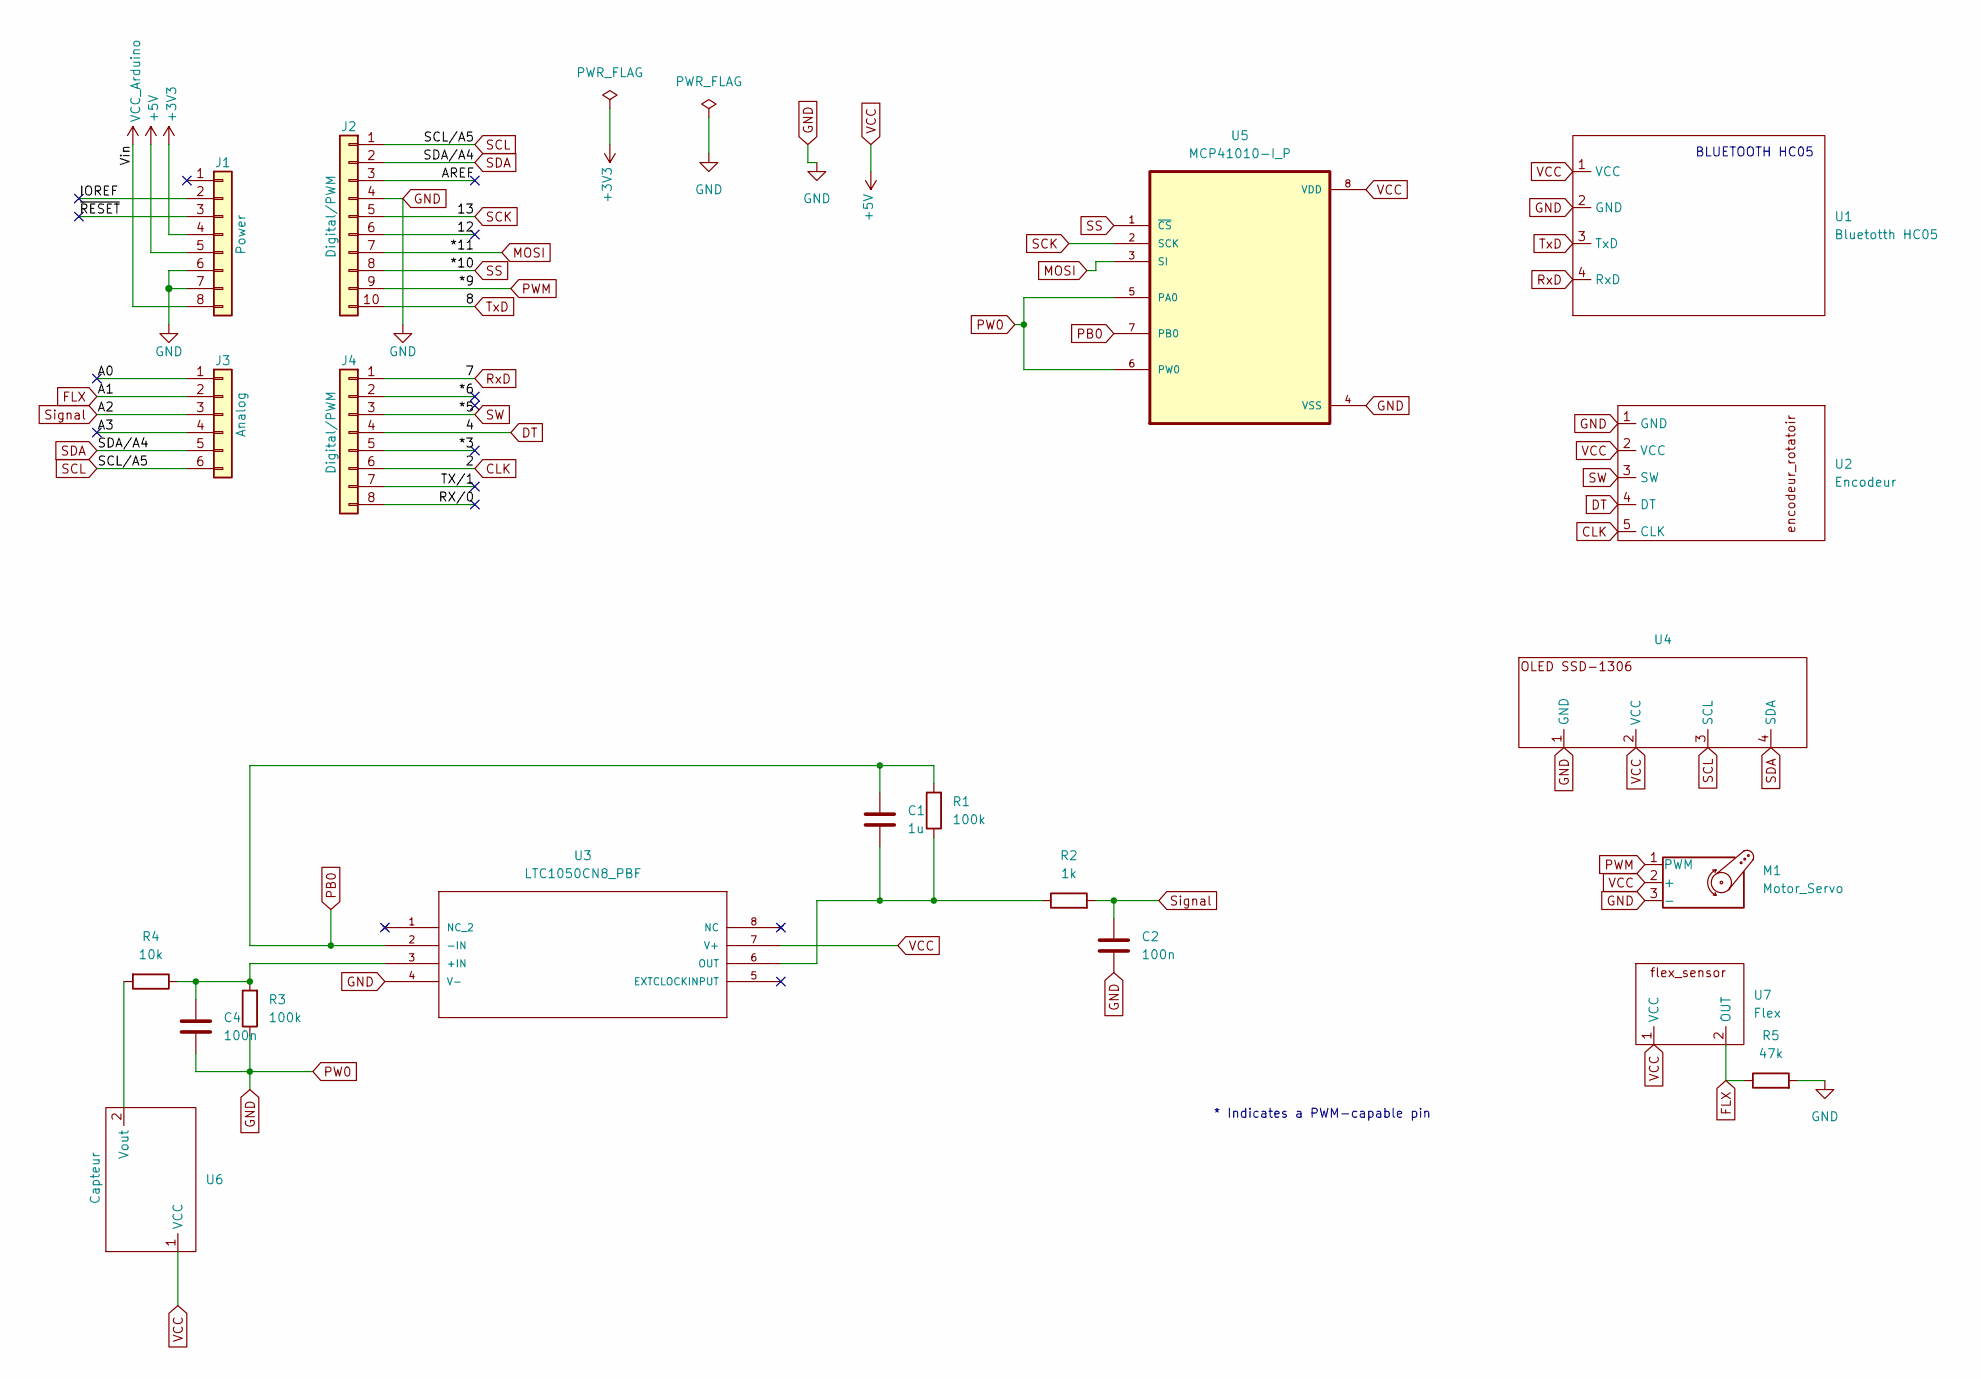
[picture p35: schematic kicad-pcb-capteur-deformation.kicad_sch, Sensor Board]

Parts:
C1: 1u; C - 5,08
C2, C4: 100n; C
J1: Power; PinSocket_1x08_P2.54mm_Vertical
J2: Digital/PWM; PinSocket_1x10_P2.54mm_Vertical
J3: Analog; PinSocket_1x06_P2.54mm_Vertical
J4: Digital/PWM; PinSocket_1x08_P2.54mm_Vertical
M1: Motor_Servo; Servo Moteur
R1, R3: 100k; R
R2: 1k; R
R4: 10k; R
R5: 47k; R
U1: Bluetotth HC05; Bluetooth HC05
U2: Encodeur; encodeur_rotatoire
U3: LTC1050CN8_PBF; LTC-1050; MANUFACTURER_PART_NUMBER ltc1050cn8
U4: OLED SSD1306
U5: MCP41010-I_P; Resistance Variable
U6: Capteur
U7: Flex; Flex Sensor

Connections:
+3V3: J1.4
/12: J2.6
/*3: J4.5
/*6: J4.2
/A0: J3.1
/A3: J3.4
/AREF: J2.3
/IOREF: J1.2
/RX/0: J4.8
/TX/1: J4.7
/~RESET: J1.3
CLK: J4.6, U2.5 (CLK)
DT: J4.4, U2.4 (DT)
FLX: J3.2, R5.1, U7.2 (OUT)
GND: C2.2, C4.2, J1.6, J1.7, J2.4, M1.3 (-), R3.1, R5.2, U1.2 (GND), U2.1 (GND), U3.4 (V-), U4.1 (GND), U5.4 (VSS), U5.5 (PA0), U5.6 (PW0)
MOSI: J2.7, U5.3 (SI)
unnamed: C4.1, R3.2, R4.1, U3.3 (+IN)
unnamed: C1.2, R1.1, R2.1, U3.6 (OUT)
unnamed: R4.2, U6.2 (Vout)
PB0: C1.1, R1.2, U3.2 (-IN), U5.7 (PB0)
PWM: J2.9, M1.1 (PWM)
RxD: J4.1, U1.4 (RxD)
SCK: J2.5, U5.2 (SCK)
SCL: J2.1, J3.6, U4.3 (SCL)
SDA: J2.2, J3.5, U4.4 (SDA)
SS: J2.8, U5.1 (~CS)
SW: J4.3, U2.3 (SW)
Signal: C2.1, J3.3, R2.2
TxD: J2.10, U1.3 (TxD)
VCC: J1.5, M1.2 (+), U1.1 (VCC), U2.2 (VCC), U3.7 (V+), U4.2 (VCC), U5.8 (VDD), U6.1 (VCC), U7.1 (VCC)
VCC_Arduino: J1.8

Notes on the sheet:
* Indicates a PWM-capable pin
BLUETOOTH HC05

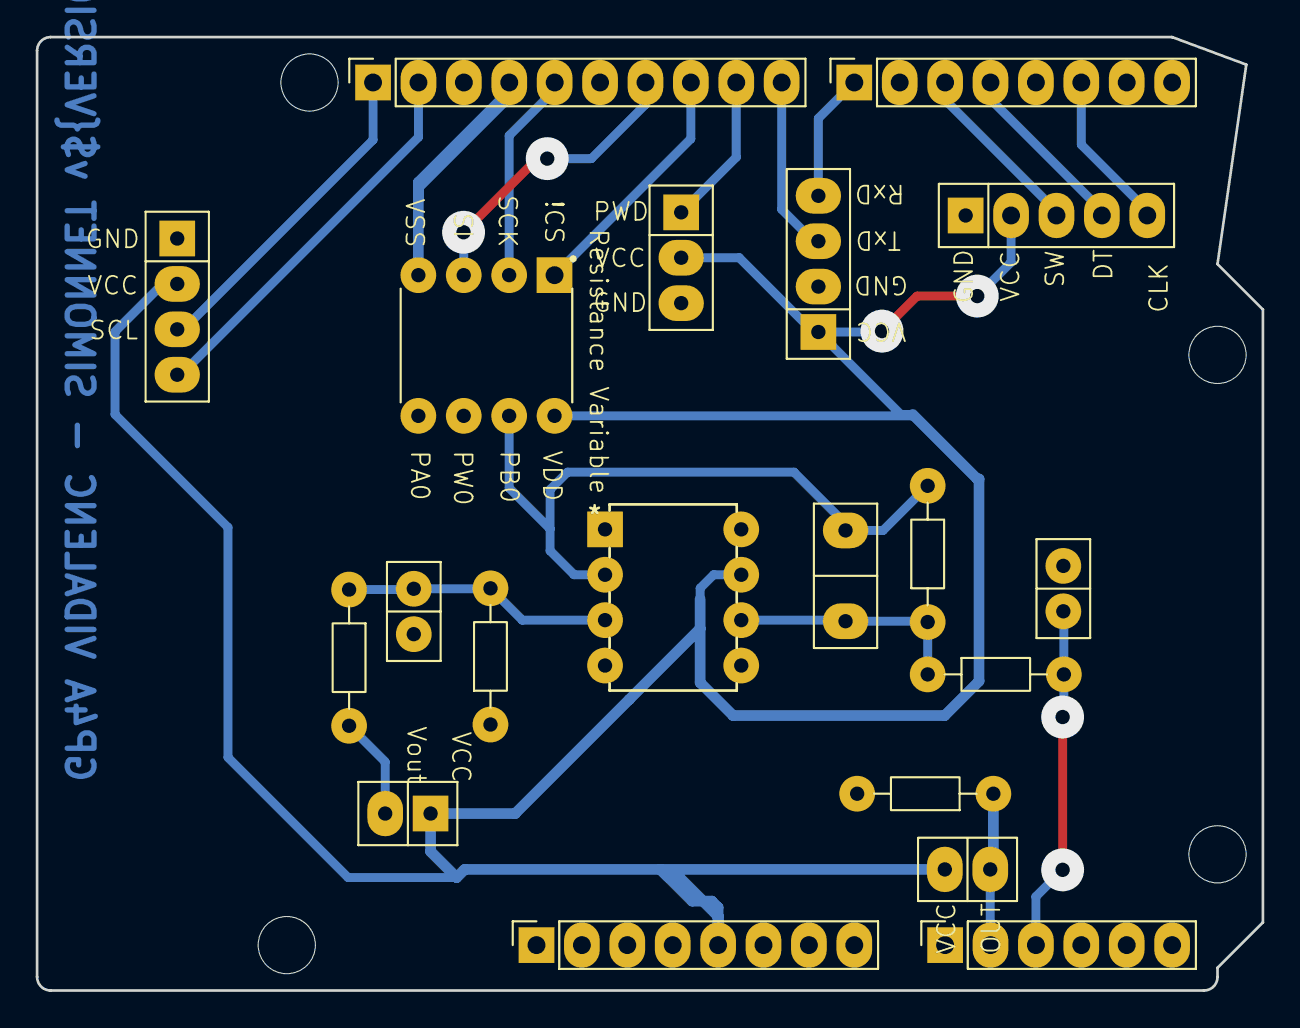
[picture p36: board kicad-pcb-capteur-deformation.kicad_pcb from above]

Board: 2 copper layers, 68.6 x 53.3 mm, 24 parts (0 on the bottom side), 19 nets.

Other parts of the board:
MH1, MH2, MH3, MH4: MountingHole_3.2mm

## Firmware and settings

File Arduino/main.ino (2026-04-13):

/*
Projet capteur - Basile Vidalenc et Max Simonnet
Code permettant l'envoie de donnée sur la résistance du potentiomètre digital, du flex sensor et du capteur à base de graphite sur un écran OLED et notre appli bluetooth et sur le serial monitor
Pour réaliser ce code nous nous sommmes inspiré du code réalisé précédement par Maël LE BLANC, Daniel PERALES RIOS. 
Lien de leur Github : https://github.com/MOSH-Insa-Toulouse/2023-2024-4GP-LE-BLANC--PERALES-RIOS
*/

#include <Adafruit_SSD1306.h>
#include <SoftwareSerial.h>
#include <SPI.h>

////////////////////////////// --- INITIALISATION DES VARIABLES --- //////////////////////////////

// --- Paramètres matériels de l'arduino ---
#define encoderPinA 2
#define encoderPinB 4
#define Switch 5
#define nombreDePixelsEnLargeur 128
#define nombreDePixelsEnHauteur 64
#define brocheResetOLED -1
#define adresseI2CecranOLED 0x3C

#define MCP_WRITE 0b00010001
#define rxPin 0 
#define txPin 1 
#define baudrate 9600

Adafruit_SSD1306 ecranOLED(nombreDePixelsEnLargeur, nombreDePixelsEnHauteur, &Wire, brocheResetOLED); 
SoftwareSerial mySerial(rxPin, txPin);
char data_[16]; // Buffer pour stocker des chaînes de caractères

// --- GRAPHITE SENSOR ---
float range = pow(10,-6);
float Vadc = 0.0;
float R1 = 100000.0;
float R3 = 100000.0;
float R5 = 10000.0;
float Rc = 0.0; // Résistance finale mesurée du capteur graphite

// --- FLEX SENSOR ---
const int flexPin = A1;
const float VCC = 5.0;
const float R_DIV = 29000.0;
const float flatResistance = 37000.0; // Résistance sans contrainte sur le flex sensor
const float bendResistance = 110000.0; // Résistance à 90°
float Rflex = 0.0;
float angle = 0.0;

// --- VARIABLES DE CONTROLE ---
int lastSwitchState = HIGH;
long lastEncoderValue = 0;
long lastPotValue = 0;
long lastDebounceTime = 0;
long debounceDelay = 40;
bool button_pressed = false;
volatile long encoderValue = 0;
volatile long encoder_for_pot = 0;

bool mainMenu = true;
const char* menuItems[] = {"Potentiometer", "Flex Sensor", "Graphite Sensor"};
int selectMenu = 0;

// --- DIGITAL POTENTIOMETER ---
const int ssMCPin = 10; // Déclaration de la Pin sur l'Arduino
float rWiper = 125.0;
float max_value_pot = 50000.0;
int valuePot = 10;
float R2 = (float(valuePot)/256.0)*max_value_pot;

/////////////////////////////////// --- SETUP --- ///////////////////////////////////
void setup() {
    Serial.begin(9600);
    
    // Définition du Bus SPI
    pinMode(ssMCPin, OUTPUT);
    digitalWrite(ssMCPin, HIGH);

    // Initialisation de l'écran
    delay(1000); // Stabilisation de la tension
    if (!ecranOLED.begin(SSD1306_SWITCHCAPVCC, adresseI2CecranOLED)) {
       Serial.println(F("OLED introuvable"));
       while (1); // Bloque le programme si l'écran ne répond pas
    }
    
    ecranOLED.clearDisplay();
    ecranOLED.setTextColor(SSD1306_WHITE);
    ecranOLED.setCursor(20, 25);
    ecranOLED.print(F("INITIALISATION..."));
    ecranOLED.display(); 

    // Initialisation des autres composants connectés à l'Arduino
    pinMode(encoderPinA, INPUT_PULLUP);
    pinMode(encoderPinB, INPUT_PULLUP);
    pinMode(Switch, INPUT_PULLUP);
    
    SPI.begin();
    mySerial.begin(baudrate);
    attachInterrupt(digitalPinToInterrupt(encoderPinA), updateEncoder, RISING);  // Lie l'interruption sur le front montant de la pin A
    
    delay(1000);
    Serial.println(F("System Ready"));
}

//////////////////////////////////// --- LOOP --- ////////////////////////////////////
void loop() {
    if (mainMenu) {
        displayMenu();
        updateSelectedItem(encoderValue, 3);
        switchButton();
    } else {
        handleMenuItemSelection(selectMenu);
        switchButton();
    }
    delay(50); // Plus réactif
}

////////////////////////////////// --- FONCTIONS DES COMPOSANTS --- //////////////////////////////////

// --- FONCTIONS AFFICHAGE ---
void displayMenu() {
    ecranOLED.clearDisplay();
    for (int i = 0; i < 3; i++) {
        if (i == selectMenu) {
            ecranOLED.setTextColor(SSD1306_BLACK, SSD1306_WHITE); // Surlignage
        } else {
            ecranOLED.setTextColor(SSD1306_WHITE);
        }
        ecranOLED.setCursor(0, i * 15);
        ecranOLED.print(menuItems[i]);
    }
    ecranOLED.display();
}

void displayPotentiometer(int val) {
    ecranOLED.clearDisplay();
    ecranOLED.setTextColor(SSD1306_WHITE);
    SPIWrite(MCP_WRITE, val, ssMCPin);
    
    ecranOLED.setCursor(0, 0);
    ecranOLED.print(F("DigiPot Setting"));
    ecranOLED.setCursor(0, 20);
    ecranOLED.print(F("R2: ")); ecranOLED.print(R2); ecranOLED.print(F(" Ohm"));
    
    ecranOLED.setCursor(0, 50);
    ecranOLED.setTextColor(SSD1306_BLACK, SSD1306_WHITE);
    ecranOLED.print(F("< BACK"));
    ecranOLED.display();
}

void displayFlexSensor() {
    ecranOLED.clearDisplay();
    ecranOLED.setTextColor(SSD1306_WHITE);
    flexMeasure();
    
    ecranOLED.setCursor(0, 0);
    ecranOLED.print(F("Flex Res: ")); ecranOLED.print(Rflex);
    ecranOLED.setCursor(0, 20);
    ecranOLED.print(F("Angle: ")); ecranOLED.print(angle);
    
    ecranOLED.setCursor(0, 50);
    ecranOLED.setTextColor(SSD1306_BLACK, SSD1306_WHITE);
    ecranOLED.print(F("< BACK"));
    
    sendBluetooth(); 
    ecranOLED.display();
}

void displayGraphiteSensor() {
    ecranOLED.clearDisplay();
    ecranOLED.setTextColor(SSD1306_WHITE);
    graphiteMeasure();
    
    ecranOLED.setCursor(0, 0);
    ecranOLED.print(F("Graphite Res:"));
    ecranOLED.setCursor(0, 20);
    ecranOLED.print(Rc); ecranOLED.print(F(" MOhm"));
    
    ecranOLED.setCursor(0, 50);
    ecranOLED.setTextColor(SSD1306_BLACK, SSD1306_WHITE);
    ecranOLED.print(F("< BACK"));
    
    sendBluetooth();
    ecranOLED.display();
}

/////////////////////////////////// --- MESURES --- ///////////////////////////////////

void graphiteMeasure() {
    float V = analogRead(A2);
    Vadc = V * 5.0 / 1023.0;
    // Formule corrigée avec flottants
    Rc = ((R1 * (1.0 + R3 / R2) * (VCC / Vadc)) - R1 - R5) * range; // Résistance finale du capteur graphite
}

void flexMeasure() {
    int ADCflex = analogRead(flexPin);
    float Vflex = (ADCflex / 1023.0) * VCC;
    Rflex = R_DIV * (VCC / Vflex - 1.0);
    angle = map(Rflex, flatResistance, bendResistance, 0, 90.0);
}

// Fonction appelée par l'interruption à chaque cran de l'encodeur
void updateEncoder() {
    if (mainMenu) {
        if (digitalRead(encoderPinB) == LOW) encoderValue++;
        else encoderValue--;
    } else if (selectMenu == 0) {
        if (digitalRead(encoderPinB) == LOW) encoder_for_pot++;
        else encoder_for_pot--;
    }
}
// Gestion de la sélection cyclique
void updateSelectedItem(int encVal, int NumberOfItems) {
    int val = abs(encVal % NumberOfItems);
    if (val != lastEncoderValue) {
        selectMenu = val;
        lastEncoderValue = val;
    }
}
// Mise à jour de la valeur numérique du potentiomètre
void updatePotentiometerValue() {
    if (encoder_for_pot != lastPotValue) {
        valuePot = constrain(valuePot + (encoder_for_pot > lastPotValue ? 5 : -5), 0, 255);
        lastPotValue = encoder_for_pot;
    }
}

void SPIWrite(uint8_t cmd, uint8_t res, uint8_t ssPin) { // Envoi effectif des données au MCP41xxx
    updatePotentiometerValue(); // On calcule d'abord la valeur
    R2 = ((max_value_pot * res) / 256.0) + rWiper; // On calcule la résistance réelle correspondante pour l'affichage 
    SPI.beginTransaction(SPISettings(1000000, MSBFIRST, SPI_MODE0)); // On démarre la transaction SPI 
    digitalWrite(ssPin, LOW); // On active le composant (CS bas)
    SPI.transfer(cmd); // On envoie l'octet de commande
    SPI.transfer(res); // On envoie la valeur de résistance 
    digitalWrite(ssPin, HIGH); // On désactive le composant (CS haut)
    SPI.endTransaction(); // On termine la transaction SPI
} 


void switchButton() {
    if (digitalRead(Switch) == LOW && (millis() - lastDebounceTime) >= debounceDelay) {
        lastDebounceTime = millis();
        mainMenu = !mainMenu; // Bascule menu principal / sous-menu
        while(digitalRead(Switch) == LOW); // Attendre relâchement
    }
}

void sendBluetooth() {
  /* * On prépare la ligne au format : Potentiometre|Flex|Graphite
   * On utilise directement les variables globales calculées dans les autres fonctions
   */

  // Envoi de la valeur R2 (Potentiomètre)
  mySerial.print(R2); 
  mySerial.print("|");
  Serial.print(R2); Serial.print("|");

  // Envoi de la valeur Rflex (Flex)
  mySerial.print(Rflex);
  mySerial.print("|");
  Serial.print(Rflex); Serial.print("|");

  // Envoi de la valeur Rc (Graphite)
  mySerial.println(Rc); 
  Serial.println(Rc);
}

// Switch pour choisir quel écran afficher
void handleMenuItemSelection(int sel) {
    switch (sel) {
        case 0: displayPotentiometer(valuePot); break;
        case 1: displayFlexSensor(); break;
        case 2: displayGraphiteSensor(); break;
    }
}

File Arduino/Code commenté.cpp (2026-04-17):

/* Projet capteur - Basile Vidalenc et Max Simonnet */ // Noms des auteurs du projet
/* Code permettant l'envoie de donnée sur la résistance du potentiomètre digital, du flex sensor et du capteur à base de graphite sur un écran OLED et notre appli bluetooth et sur le serial monitor */ // Description globale des fonctionnalités du code
/* Pour réaliser ce code nous nous sommmes inspiré du code réalisé précédement par Maël LE BLANC, Daniel PERALES RIOS. */ // Mention des étudiants dont le travail a servi de base
/* Lien de leur Github : https://github.com/MOSH-Insa-Toulouse/2023-2024-4GP-LE-BLANC--PERALES-RIOS */ // Lien vers le projet de référence

#include <Adafruit_SSD1306.h> // On importe la librairie pour piloter l'écran OLED
#include <SoftwareSerial.h> // On utilise cette librairie pour créer un port série logiciel pour le Bluetooth
#include <SPI.h> // Inclusion de la librairie pour la communication SPI avec le potentiomètre

////////////////////////////// --- INITIALISATION DES VARIABLES --- ////////////////////////////// // Section de déclaration des variables

// --- Paramètres matériels de l'arduino --- // Définition des branchements physiques
#define encoderPinA 2 // Branchement de la broche A de l'encodeur rotatif sur le pin 2
#define encoderPinB 4 // Branchement de la broche B de l'encodeur rotatif sur le pin 4
#define Switch 5 // Le bouton de l'encodeur est relié au pin 5
#define nombreDePixelsEnLargeur 128 // L'écran fait 128 pixels de large
#define nombreDePixelsEnHauteur 64 // L'écran fait 64 pixels de haut
#define brocheResetOLED -1 // On n'utilise pas de pin de reset pour l'OLED
#define adresseI2CecranOLED 0x3C // Adresse I2C standard pour ce type d'écran

#define MCP_WRITE 0b00010001 // Commande pour écrire dans le registre du MCP41xxx
#define rxPin 0 // Définition de la pin de réception série (attention, déjà utilisée par l'USB)
#define txPin 1 // Définition de la pin de transmission série
#define baudrate 9600 // Vitesse de communication standard à 9600 bauds

Adafruit_SSD1306 ecranOLED(nombreDePixelsEnLargeur, nombreDePixelsEnHauteur, &Wire, brocheResetOLED); // Création de l'objet pour l'écran
SoftwareSerial mySerial(rxPin, txPin); // Création du port série logiciel pour le module Bluetooth
char data_[16]; // Buffer pour stocker des chaînes de caractères si besoin

// --- GRAPHITE SENSOR --- // Variables liées au capteur graphite
float range = pow(10,-6); // Facteur d'échelle pour convertir en MegaOhms
float Vadc = 0.0; // Variable pour stocker la tension mesurée par l'ADC
float R1 = 100000.0; // Valeur de la résistance R1 du montage
float R3 = 100000.0; // Valeur de la résistance R3
float R5 = 10000.0; // Valeur de la résistance R5
float Rc = 0.0; // Variable de stockage pour la résistance calculée du capteur
// Résistance finale mesurée du capteur graphite // Commentaire indicatif sur Rc

// --- FLEX SENSOR --- // Variables liées au capteur de flexion
const int flexPin = A1; // Le capteur flex est branché sur l'entrée analogique A1
const float VCC = 5.0; // Tension d'alimentation du circuit
const float R_DIV = 29000.0; // Valeur de la résistance fixe du pont diviseur
const float flatResistance = 37000.0; // Résistance mesurée quand le capteur est plat
const float bendResistance = 110000.0; // Résistance mesurée quand le capteur est plié à 90 degrés
float Rflex = 0.0; // Variable pour la résistance calculée du flex sensor
float angle = 0.0; // Variable pour stocker l'angle de flexion calculé

// --- VARIABLES DE CONTROLE --- // Variables pour la navigation et l'encodeur
int lastSwitchState = HIGH; // État précédent du bouton pour détecter l'appui
long lastEncoderValue = 0; // Dernière valeur connue de l'encodeur pour le menu
long lastPotValue = 0; // Dernière valeur de l'encodeur pour le potentiomètre
long lastDebounceTime = 0; // Timer pour filtrer les rebonds du bouton
long debounceDelay = 40; // Délai de 40ms pour le debounce
bool button_pressed = false; // Flag pour savoir si le bouton est activé
volatile long encoderValue = 0; // Valeur de l'encodeur pour le menu principal (volatile car modifiée par interruption)
volatile long encoder_for_pot = 0; // Valeur de l'encodeur dédiée au réglage du potentiomètre

bool mainMenu = true; // Booléen pour savoir si on affiche le menu ou un capteur
const char* menuItems[] = {"Potentiometer", "Flex Sensor", "Graphite Sensor"}; // Tableau contenant les noms des options du menu
int selectMenu = 0; // Index de l'élément actuellement sélectionné
// --- DIGITAL POTENTIOMETER --- // Configuration du potentiomètre numérique
const int ssMCPin = 10; // Pin Slave Select (Chip Select) pour le bus SPI sur le pin 10
float rWiper = 125.0; // Résistance interne du curseur (wiper) du MCP
float max_value_pot = 50000.0; // Valeur maximale de la résistance du potentiomètre (50k)
int valuePot = 10; // Valeur initiale du réglage (0 à 255)
float R2 = (float(valuePot)/256.0)*max_value_pot; // Calcul théorique initial de R2
/////////////////////////////////// --- SETUP --- /////////////////////////////////// // Initialisation au démarrage
void setup() { // Fonction setup exécutée une seule fois
    Serial.begin(9600); // On lance la communication série pour le débuggage
// Définition du Bus SPI // Commentaire sur le SPI
    pinMode(ssMCPin, OUTPUT); // On configure la pin CS du potentiomètre en sortie
    digitalWrite(ssMCPin, HIGH); // On la met au repos (état haut)

    // Initialisation de l'écran // Paramétrage de l'OLED
    delay(1000); // Petite pause de sécurité pour le hardware
// Stabilisation de la tension // Commentaire sur la tension
    if (!ecranOLED.begin(SSD1306_SWITCHCAPVCC, adresseI2CecranOLED)) { // On tente de démarrer l'écran
       Serial.println(F("OLED introuvable")); // Si ça échoue, on l'affiche sur le PC
while (1); // On bloque le programme ici si l'écran ne répond pas
    }
    
    ecranOLED.clearDisplay(); // On efface ce qu'il y a sur l'écran
    ecranOLED.setTextColor(SSD1306_WHITE); // On configure le texte en blanc
    ecranOLED.setCursor(20, 25); // On place le curseur au milieu
    ecranOLED.print(F("INITIALISATION...")); // On affiche un message d'attente
    ecranOLED.display(); // On envoie l'image à l'écran
// Initialisation des autres composants connectés à l'Arduino // Setup des entrées/sorties
    pinMode(encoderPinA, INPUT_PULLUP); // Pin A en entrée avec résistance de pull-up interne
    pinMode(encoderPinB, INPUT_PULLUP); // Pin B en entrée avec résistance de pull-up interne
    pinMode(Switch, INPUT_PULLUP); // Bouton en entrée avec résistance de pull-up interne
    
    SPI.begin(); // On démarre le bus SPI
    mySerial.begin(baudrate); // On démarre la communication Bluetooth
attachInterrupt(digitalPinToInterrupt(encoderPinA), updateEncoder, RISING); // On lie l'interruption sur le front montant de la pin A
    
    delay(1000); // Attente avant de lancer la boucle principale
    Serial.println(F("System Ready")); // Confirmation dans le moniteur série
}
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

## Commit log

2026-02-11 premiers symboles et construction du pcb
    [10-Pin Header - Female - 2.54mm.step, 11-Pin Header - Female - 2.54mm.step, 12-Pin Header - Female - 2.54mm.step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]
2026-02-18 empreintes et début de wiring KiCad
    [MCP41010-I_P.step, OLED 128x64.STP, OLED-128x64-0.96.step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]
2026-02-18 ignorer les maj des fichiers KiCad
2026-02-18 PCB fini
    [kicad-pcb-capteur-deformation.kicad_pcb, kicad-pcb-capteur-deformation.kicad_sch]
2026-03-03 maj des fichiers KiCad, VF préliminaire
    [kicad-pcb-capteur-deformation.kicad_pcb, kicad-pcb-capteur-deformation.kicad_sch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]
2026-03-03 dossier Arduino et maj README
2026-03-03 complété dossier Images et 3D Models sur KiCad
    [2.54 5PIN 90.SLDPRT, D-handle.SLDPRT, HC05.SLDPRT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]
2026-04-08 ajout d'images
    [kicad-pcb-capteur-deformation.kicad_sch]
2026-04-10 Resultats du capteur graphite
    [Résultats.xlsx]
2026-04-13 ajout du main.ino et calibration_R2.ino
2026-04-13 ajout datasheet
    [Résultats.xlsx]

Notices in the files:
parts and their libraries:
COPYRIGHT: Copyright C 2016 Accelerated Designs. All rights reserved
